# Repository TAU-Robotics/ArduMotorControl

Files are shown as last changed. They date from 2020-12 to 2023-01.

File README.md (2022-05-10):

# Discrete Control Lab
Discrete control experiment developed for the control lab at Tel Aviv University
The setup uses an Arduino Uno micro controller, micro dc gear motor with magnetic encoder and SparkFun Ardumoto shield.

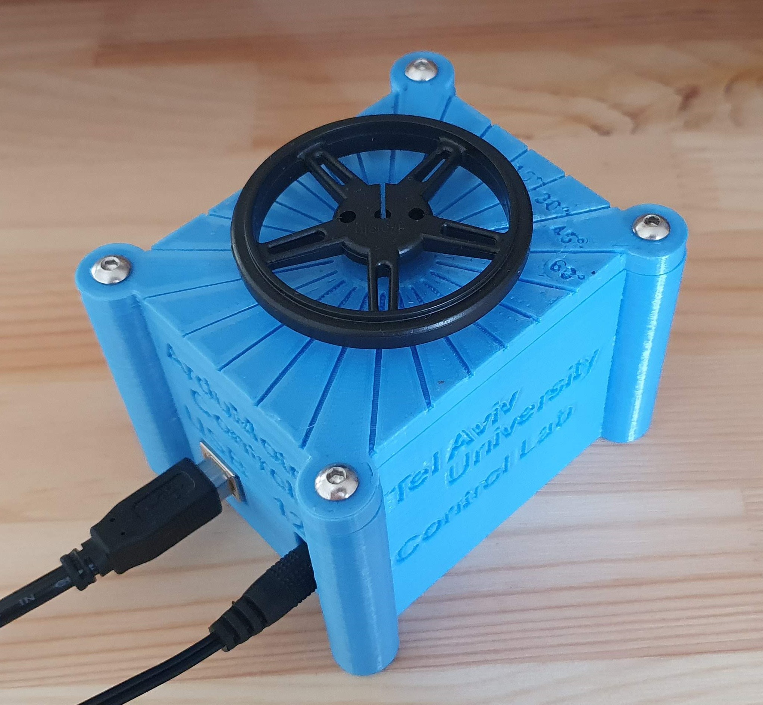
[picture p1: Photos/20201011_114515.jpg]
DC Motor Control Setup


The experiment has two parts, Simulation in simulink matlab and a hardware setup with arduino.

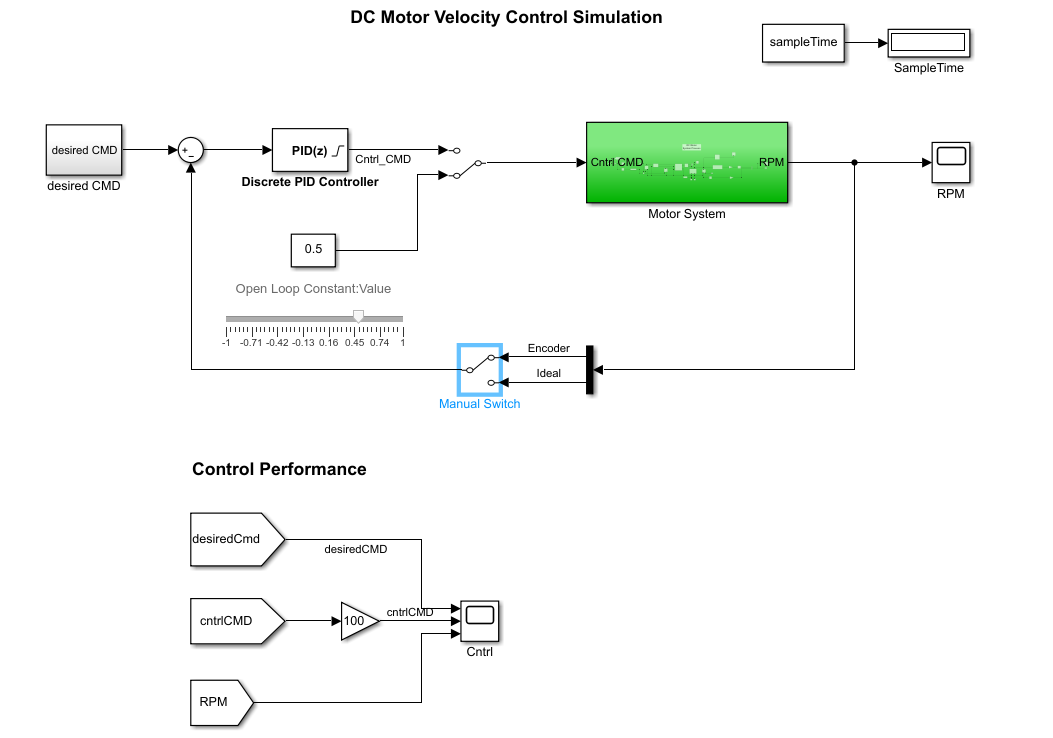
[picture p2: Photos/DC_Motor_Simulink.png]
Simulink


Simulation response:

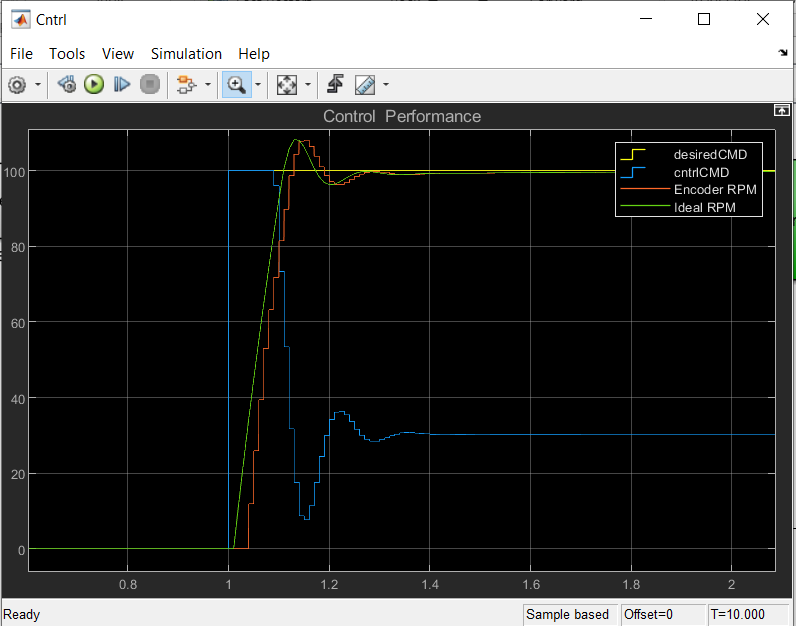
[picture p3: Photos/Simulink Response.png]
Simulink Response


Arduino response:

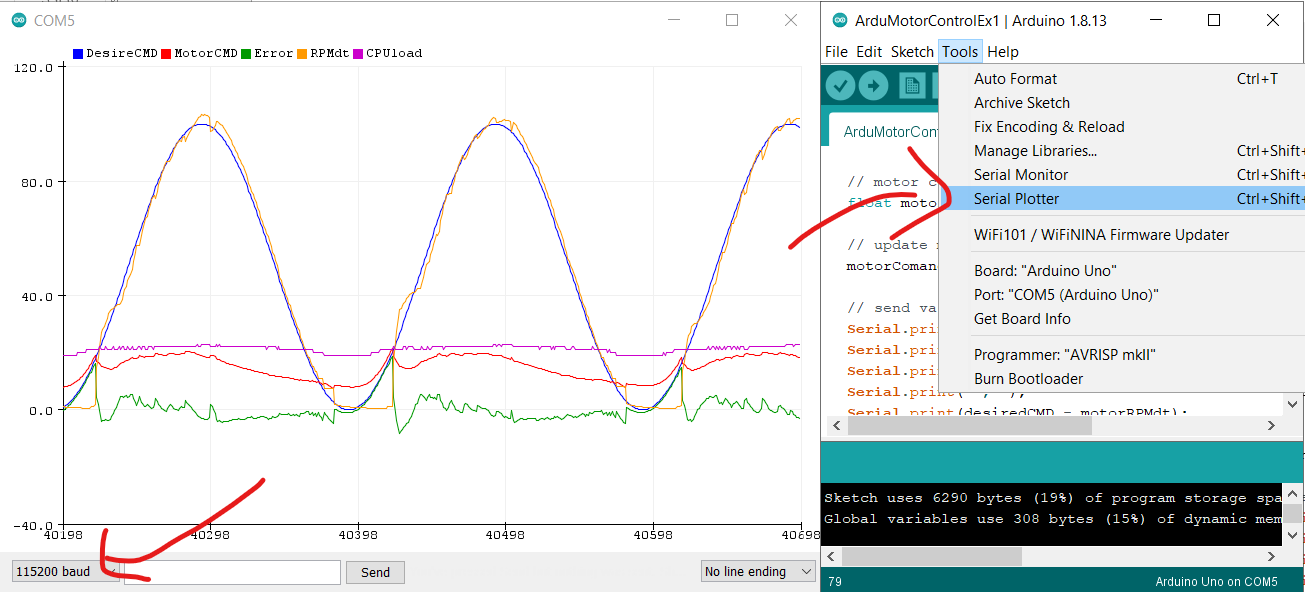
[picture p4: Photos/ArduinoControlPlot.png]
Arduino Response

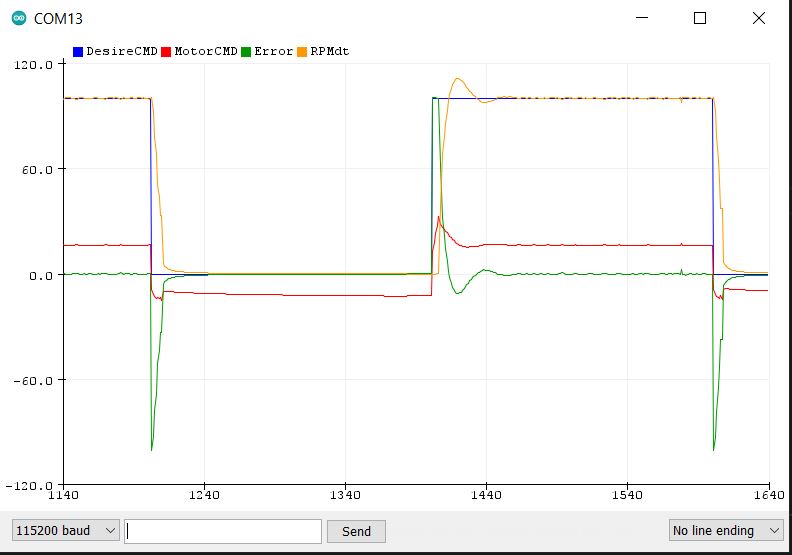
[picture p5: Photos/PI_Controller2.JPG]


# HomeKit Motor Control
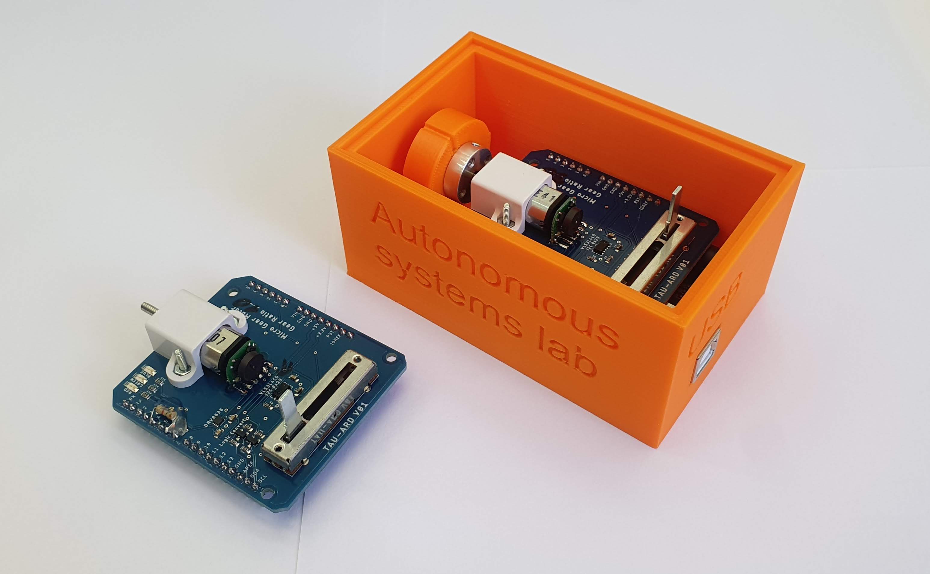
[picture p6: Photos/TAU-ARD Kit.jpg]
TAU-ARD


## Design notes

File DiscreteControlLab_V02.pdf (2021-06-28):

The Iby and Aladar Fleischman Faculty of Engineering Tel Aviv University

# Discrete Control Lab

## 1. Introduction

Modern control systems are realized using a micro controller unit (MCU) and implemented in code. Since an MCU is a discrete system, the control implementation is also a discrete control system. In this experiment, you will get a taste of implementing a simple motor control system using an Arduino development board with the Arduino development environment (IDE).

## 2. System overview

The experiment setup consists of Arduino Uno development board with a carrier shield for motor driver, a DC motor including a gearbox, encoder and a rotation mass. The control is implemented in code using an Arduino development environment in C++. For thorough description of the experiment concepts see literature review chapter. System components:
- Arduino Uno Micro Controller Unit (MCU): https://store.arduino.cc/arduino-uno-rev3
- Motor Driver Shield (H-bridge): https://www.sparkfun.com/products/14129
- DC Motor including Gear box 1:100, 1:50, 1:30 etc: https://www.pololu.com/product/3041
- Magnetic Encoder with 3PPR (Pulses Per Revolution) : https://www.pololu.com/product/3081
- Rotating mass Flywheel:
https://www.pololu.com/product/1420
- 12V Power supply:
- https://www.4project.co.il/product/wall-adapter-power-supply-12v-1a (https://www.4project.co.il/product/wall-adapter-power-supply-12v-1a)

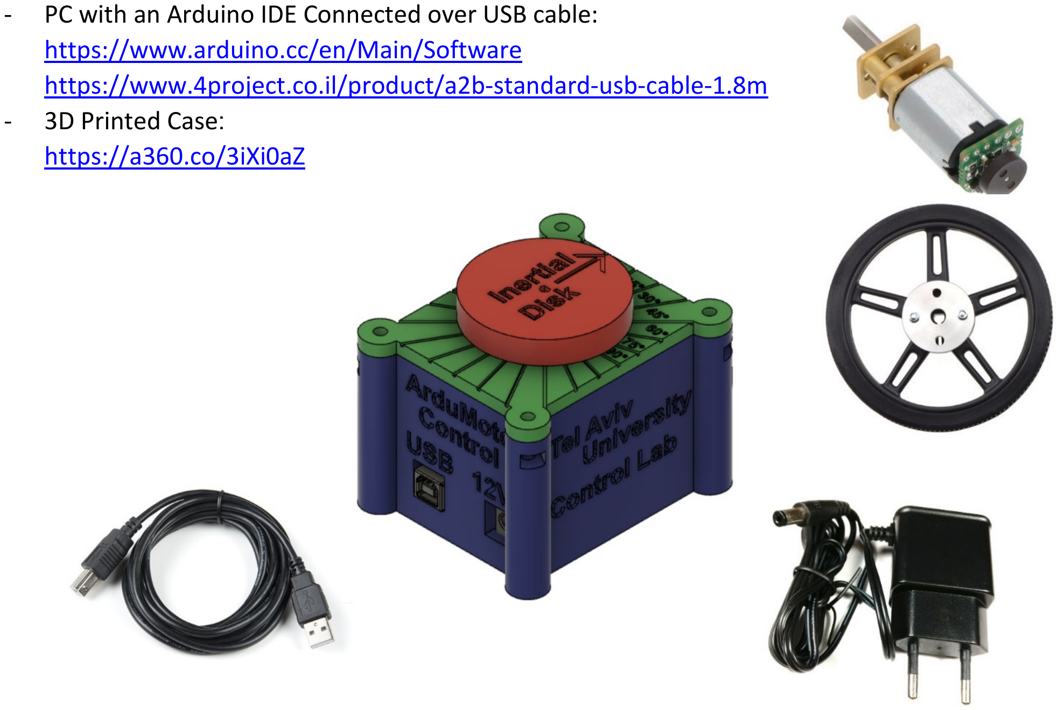
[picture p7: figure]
https://www.arduino.cc/en/Main/Software; - 3D Printed Case: https://a360.co/3iXi0aZ

- PC with an Arduino IDE Connected over USB cable:

https://www.4project.co.il/product/a2b-standard-usb-cable-1.8m

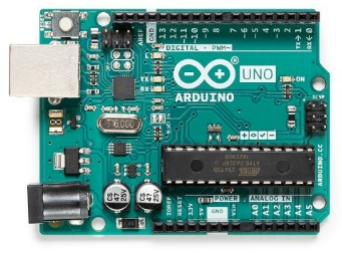
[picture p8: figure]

## 3. Discrete Control Part 1 – Simulation

Throughout this section we are going to explore the concepts of a DC motor system and learn the implementation of a discrete velocity motor control by employing a simulation in Simulink. We will get familiar with the concepts of a sampled system and its influence on the control performance.

3.1 Matlab Simulation review, Open loop.
Start by opening Simulink model: dcMotorControlSim.slx, the model contains open and closed loop implementation of a motor velocity control. The model relies on an initialization script dcMotorControlInit.m, which sets the system sample time variable. Make sure it is present in the work folder which contains the simulation model.

Run the model in open loop with various motor command values. You may change the stop time of the simulation to inf. and change the values through the slider while the simulation is running. Note the motor RPM calculation as measured by the Encoder compared to the Actual RPM.

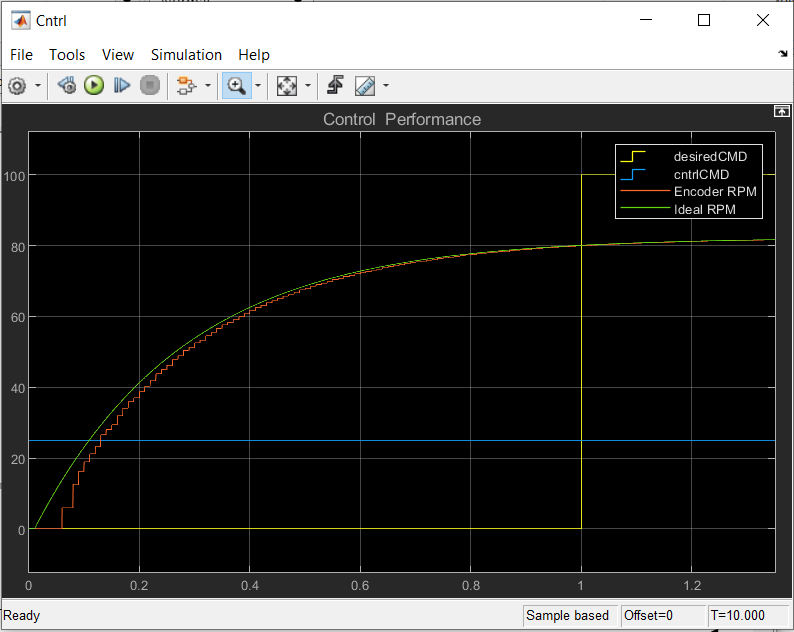
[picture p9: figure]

Change the system’s sampleTime variable and note the influence on the Encoder RPM calculation. You can update the variable through the Command window in Matlab.

Open loop with motor command at 0.25 Simulation sampleTime 0.01 sec

Open loop with motor command at 0.25 Simulation SampleTime 0.1 sec

Open the simulation subsystem named Motor System and review how it is implemented and it`s subsystems. Explain how the encoder works and how the motor velocity is calculated.
Hint: it is implemented at dcMotorControlSim/Motor System/Hall Effect Sensor/Decoder/Pulse decode.

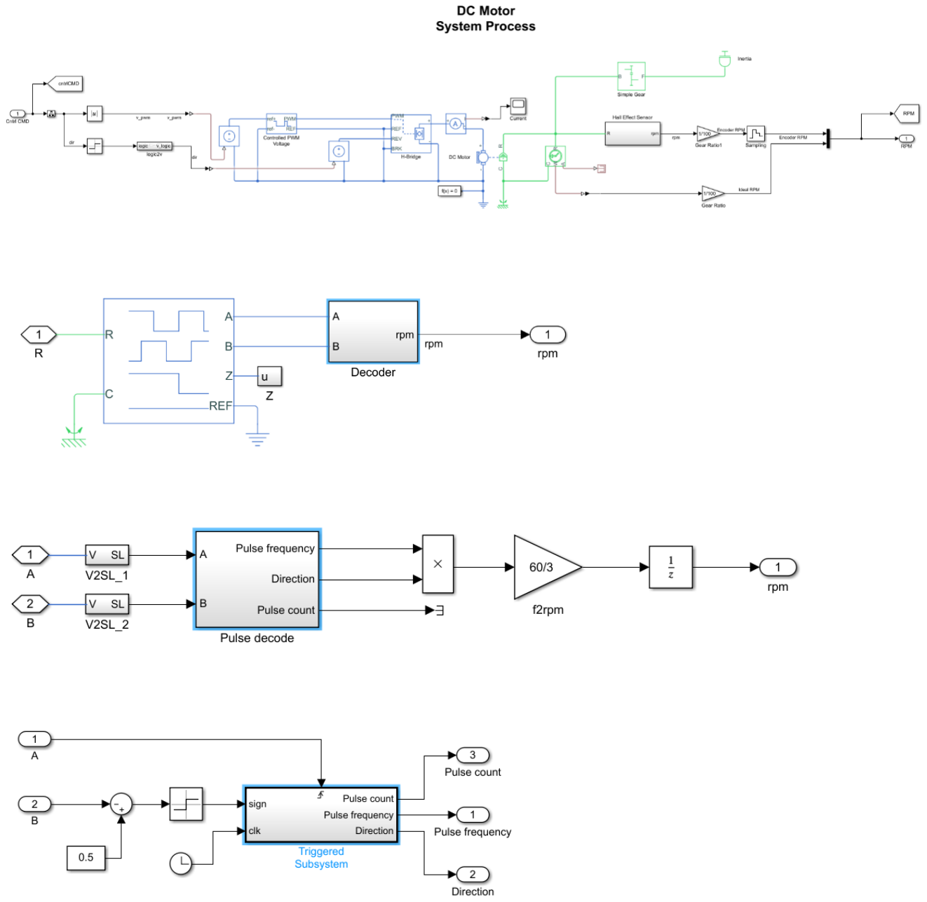
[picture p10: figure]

3.2 Close loop proportional control
For this part of the experiment we will consider the system as a black box -without a known continuous model and learn how to manually tune the controller to achieve the desired system response. First route the model switches to use the signals from the PID controller output, and for the feedback the Ideal RPM value, as depicted in the figure below. Make sure to change back the simulation sample time to 0.01 sec.

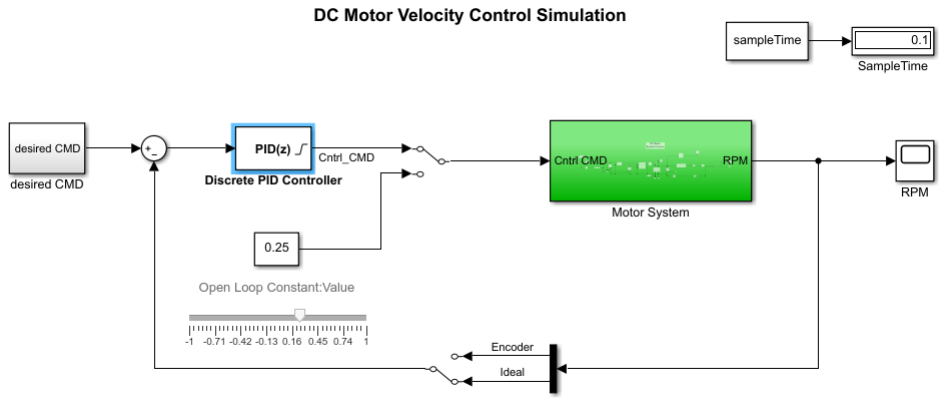
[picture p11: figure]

For this simulation a discrete implementation of the PID controller is used (the block PID(z)). Open the PID block and set it to a proportional gain only.

dcMotorContrlSim.slx, set for PID feedback

Evaluating the initial value for the proportional gain: at the previous section, we have used various motor commands values, which resulted in various motor velocities. From the model review section, you may have noticed that the PWM command is scaled by a value of 0 to 1. Zero for 0-duty cycle – Motor is off and one for 100% duty cycle – Motor works in full power. For a 0.25 value, we got a response of approximately 80 RPM. Meaning that a rational starting value for a step response of 100RPM will be at the proximity of 0.01 gain. The reasoning is that for a starting error of 100 we will get a starting motor command of 1 which is equivalent to 100% duty cycle. Run the simulation with various gains and review the response.

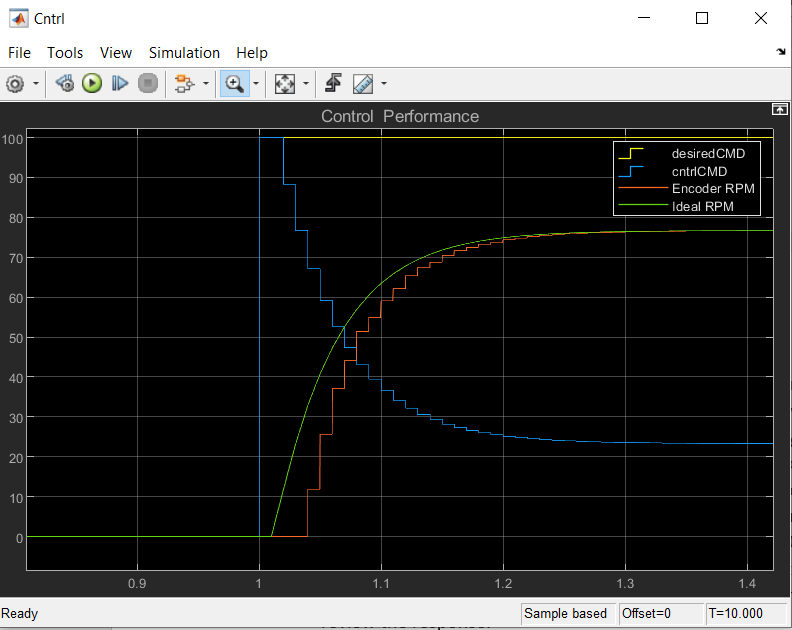
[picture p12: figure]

Close loop response Ideal RPM feedback, kP=0.01 SampleTime=0.01

Choose a proper response gain which results in a slight overshoot and switch to the Encoder feedback. What have happened? The system has lost stability. Perform the experiment with various gains and review the system response you get. Change the sample time and see what happens, run the experiment at different settings (10 gains values and 5 sampleTime values ranging at 0.1-0.001sec) make conclusion for best gains at various sample rate.

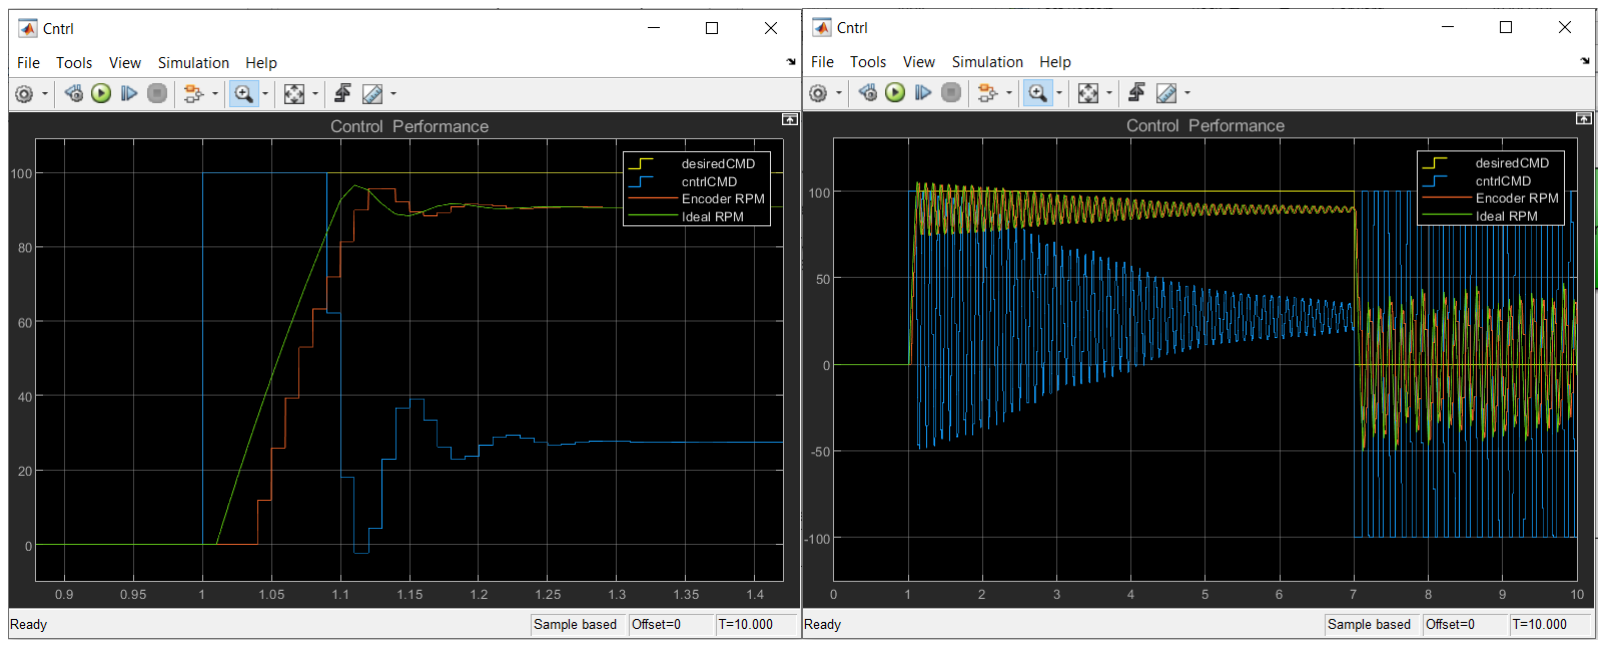
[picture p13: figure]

Because the experiment is based on discrete system implementation and uses an encoder, the system under study can no longer considered to be linear. Write down several rules of thumb concluded from the experiments for a proper proportional gain value.
- Consider the rise time as a function of the control loop frequency (sampleTime).
- Consider the Encoder resolution influence.

Ideal fedback vs Encoder feedback. kP=0.05, sampleTime=0.01

3.3 Close loop PID tuning
After setting a proper response with a proportional gain controller, our next objective is to improve the response by adding the integral and differential component of the PID controller. Set the model to encoder feedback and sampleTime variable of 0.01sec.
First, we would like to eliminate the steady state error. Begin with adding an integral term and scale the proportional gain. Gradually increase the gain and review the system response. If the system loses stability, you may consider to slightly reduce the proportional gain (explain this phenomena). Tune the system until you get a rise time of 0.1 sec, overshoot of up to 10% and settling time of 0.2 sec.

The differential gain isn`t mandatory for a velocity control loop of a DC motor but you may consider adding it to slightly reduce the system overshoot. A good starting point will be at the range of kp*sampleTime.

You may have noticed that the controller is lacking stability at low velocity, which isn`t an issue when using an ideal feedback. In the final report, discuss the reasons for this phenomenon. For the actual experiment we will be using a slightly improved method for velocity estimation based on the encoder feedback, therefore the simulation will be slightly more robust at low velocities.

3.4 PID code implementation
Open Simulink model dcMotorControlSimPIDcode.slx. Note that it has a Matlab function for implementing the PID control in code. Route the system Control command to the Matlab PID function. It has the implementation of proportional gain only. Review the code and complete it for the full PID implementation (add the integral and derivative terms). Compare the response between the Simulink block and the code implementation that you have just completed for identical PID values.

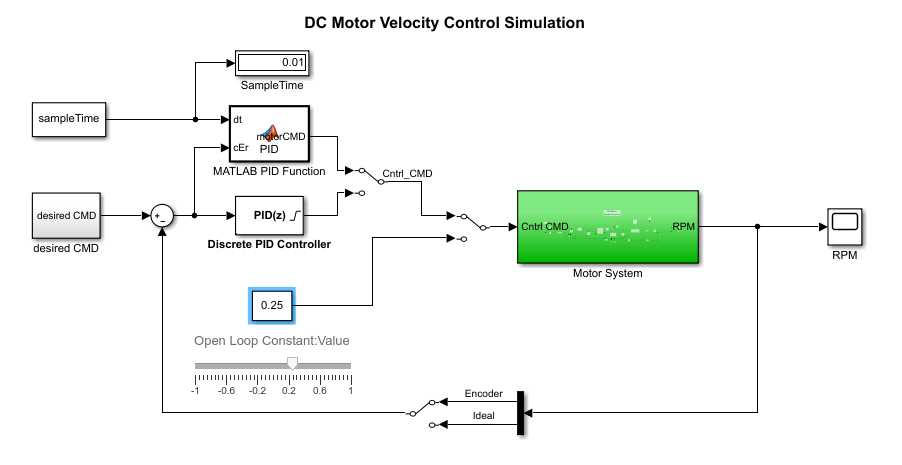
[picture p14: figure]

function motorCMD = PID(dt,cEr)
% persistant variables persist between function calls. similar to % static variable declaration in c
persistent lEr cdEr ciEr;
if isempty(lEr) %initialize variables for first run of the code. lEr = 0; % previous error initialization
cdEr = 0; % differantional error initialization
ciEr = 0; % integral error initialization
end
% control coeficients
kp = 0.025;
% clip integrator error
if (ciEr > 10)
ciEr = 10;
elseif (ciEr < -10)
ciEr = -10;
end
% update control command
motorCMD = kp*cEr;
% clip motor command
if (motorCMD > 1)
motorCMD = 1;
elseif (motorCMD < -1)
motorCMD = -1;
end
% update last error variable before next iteration lEr = cEr;

## 4. Discrete Control Part 2 – Hardware

In this section we will implement the control laws using the Arduino IDE (Integrated Development Environment) in C++ and monitor its response by employing the embedded tool of the IDE. Since most of the modern control systems use a micro controller for motor control this experiment will be a good peek into the actual implementations of the learned theories during the classes.
4.1 Getting started with Arduino / Arduino IDE
Open Arduino IDE, either use the desktop icon, or search for the application.

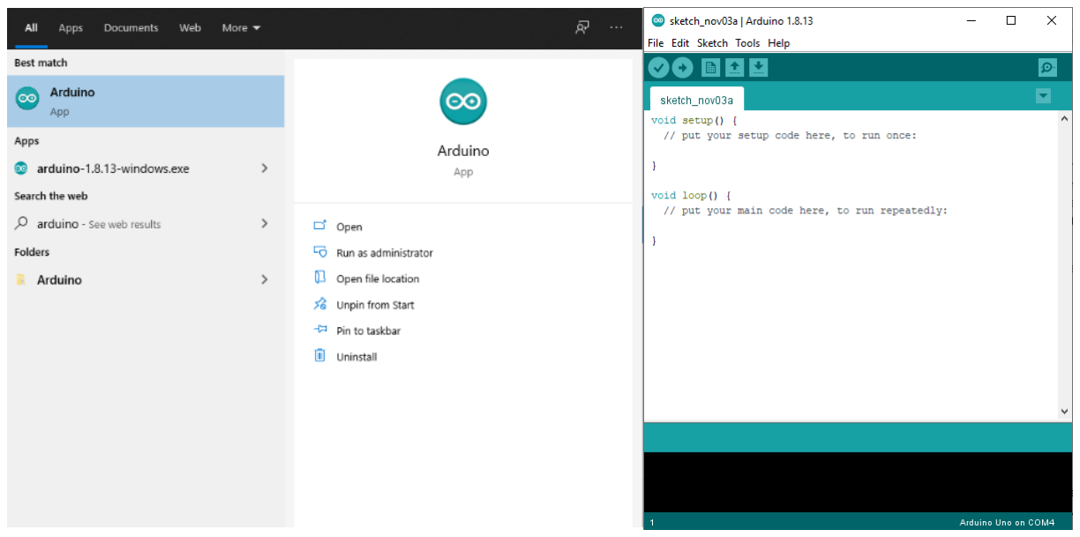
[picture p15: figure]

Connect the USB cable to the ArduMotoControl Box. Since the micro controller implement the last code that has been uploaded, you may see the motor start spinning upon voltage application. Make sure that the 12V power plug is also connected. When you finish working with the setup, disconnect the power supply and the USB cable.

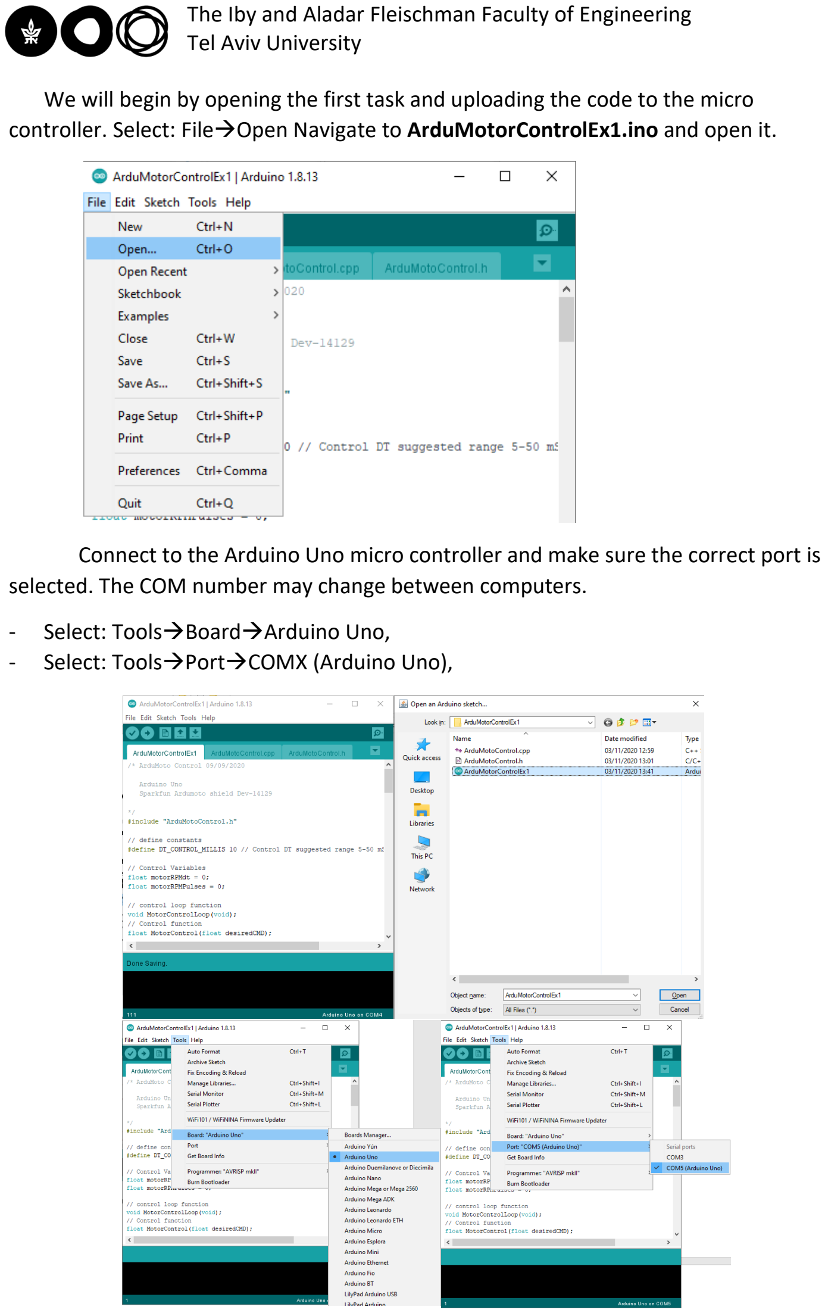
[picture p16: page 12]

We will begin by opening the first task and uploading the code to the micro controller. Select: File→Open Navigate to ArduMotorControlEx1.ino and open it.

Connect to the Arduino Uno micro controller and make sure the correct port is selected. The COM number may change between computers.
- Select: Tools→Board→Arduino Uno,
- Select: Tools→Port→COMX (Arduino Uno),

Upload the example to the micro controller by pressing upload button→. If everything is successful than you should see the “Done uploading” message and the motor will start spinning with a Sine Profile.

View the System response using the Serial Plotter tool. Make sure the baud rate is set to 115200 otherwise you get gibberish on the screen instead of the desired data. If everything has started correctly you will see the legend of the data on top of the graph, if it is mixed due to incorrect baud rate or some other start up issue you may reopen the Serial Plotter. It will reset the controller and start correctly.
- Tools→ Serial Plotter

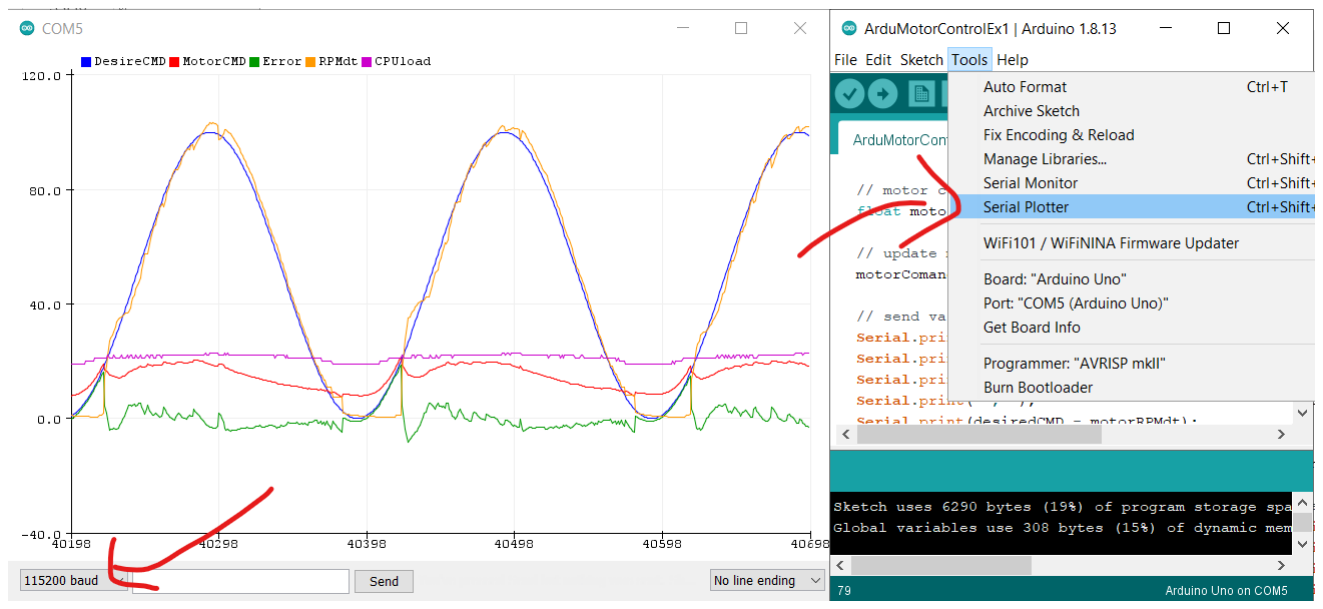
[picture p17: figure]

You may notice that the RPM readings do not correspond to the actual rotating speed of the disc. Don`t worry, in the next section we will set the correct gear ratio for the specific box and verify that it is corresponds to what we perceive.

Sometimes during the lab, you will be required to record a series of data, for that we will use the Serial Monitor tool. Each time you open the Serial Monitor or the Serial Plotter tool it will reset the micro controller and restart the latest code uploaded to it. When you open the Serial Monitor you will be able to see the streamed values, make sure the baud rate is correct and in order to make a recording deselect the Auto-scroll feature or wait for the motor to finish spinning. Select the data set by pressing CTRL+A and CTRL+C, Past the data set into a text file you have created on the pc.
- Tools→ Serial Monitor

You may notice that the recorded data has unfished data at the button of the data set or some values prior the variable names, which are of a previous session (prior reopening the Serial Monitoring tool). In order to make it easier to import the data into Matlab we will preprocess the data set by deleting all the values prior the variable names and the last unfinished line.

At this point importing the data into Matlab is easy using the Matlab Import Data tool. Press the Import Data option select the processed file, make sure the Comma separating is selected and import the samples to the workspace. To preview the recorded samples, use the Matlab stacked plot option. Right click on the data set in Matlab select Plot Catalog and choose the stacked plot option.

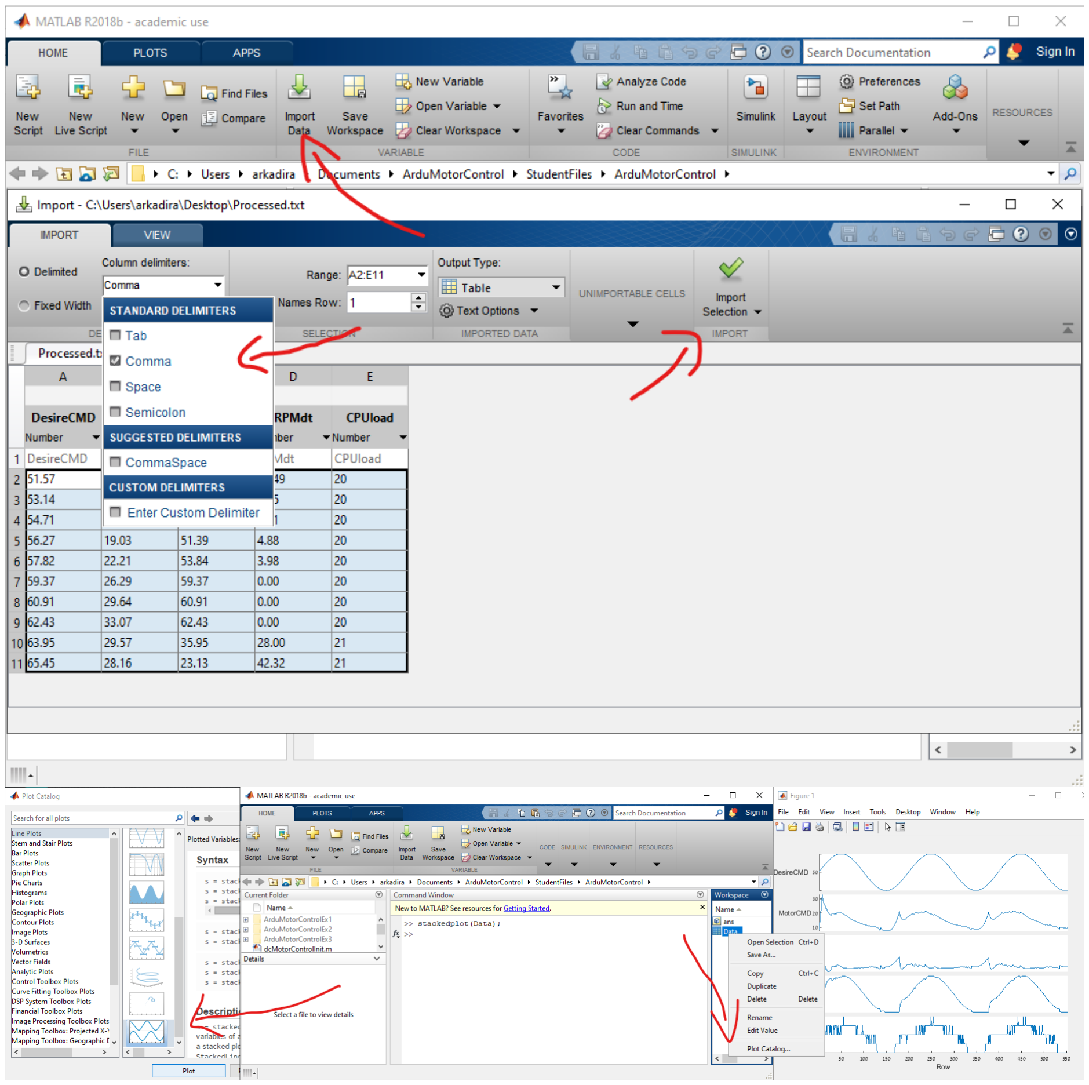
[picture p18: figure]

4.2 Code Review
The Experiment is implemented in C++ in order to handle the control section we will review the general approach for the code. When opening the ArduMotorControlEx1 you may have noticed the added files ArduMotoControl.cpp and ArduMotoControl.h those are the library files for the experiment and they have the implementation of the functions available at the main file ArduMotorControlEx1 including the motor driver handling and the encoder reading. You may review them and the comments for each function but for the experiment we will focus at the code in the main file.
The file Starts with the #include line for the library following some variables and function declaration. Make notice of the following variables, function.
- DT_CONTROL_MILLIS – Sets the control interval for the experiment similar to the simulation. Take care not to exceed the recommended settings as not to overload the CPU. (Nothing will break but the controller will lose its stability)
- GEAR_RATIO – Sets the gear ration for the specific setup. The gear ratio is written on the box of the experiment.
- TIMEOUT – Sets the time for the experiment in seconds.
- motorRPMdt – Is a global variable for the motor velocity based on the time interval between encoder pulses.
- motorRPMPulses – Is a global variable for the motor velocity based on the number of pulses occurred between the calls of the readRadSEncoder() function
- MotorControlLoop – Is a function which is called every controlled interval set by the DT_Control_Millis.
- MotorControl – Is the actual function for the Control implementation called inside the MotorControlLoop function.
Note the sections which start and end with the comment Student Code / Student Function, they indicate the sections which are available for modification so as not to harm the general flow of the rest of the code.

4.3 Open loop velocity response & Encoder readings
For this section we will evaluate the system response and understand the limitation of working with a cheap encoder, start by Opening the ArduMotorControlEx2.ino sketch in the Arduino environment. Review the code and update the GEAR_RATIO parameter to correspond to the gear ratio written on the box.

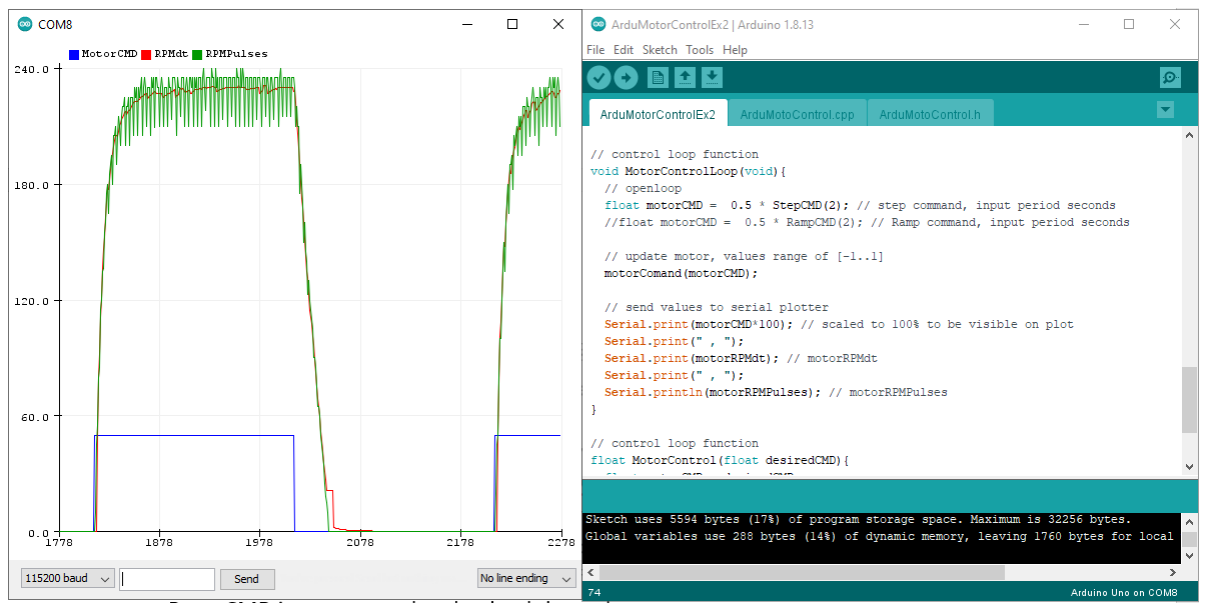
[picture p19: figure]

Find the Open loop command inside the MotorControlLoop() function. We will work with a ramp command and step command functions which are implemented in the library, the input to the function is the time period and the output is a command in the range of [0..1]. Verify that the StepCMD() function is uncommented with a gain of 0.5 and the RampCMD is commented and upload the code. Open the Serial Plotter and view the system response. The plot contains the desired command, the velocity
measurement using the two approaches, time between encoder pulses, and number of pulses per function call RPMdt, RPMPulses.
For a gear ratio of 1:100 you should get RPM value of ~210 RPM for a gear ratio 1:30 approximately ~700 RPM. To verify that you have set the GEAR_RATIO correctly you may set a lower open loop gain and count the number of motor revolutions for a period of time. Than estimate if it corresponds to the measured value.
RPM = Revolution*60/Time[s].

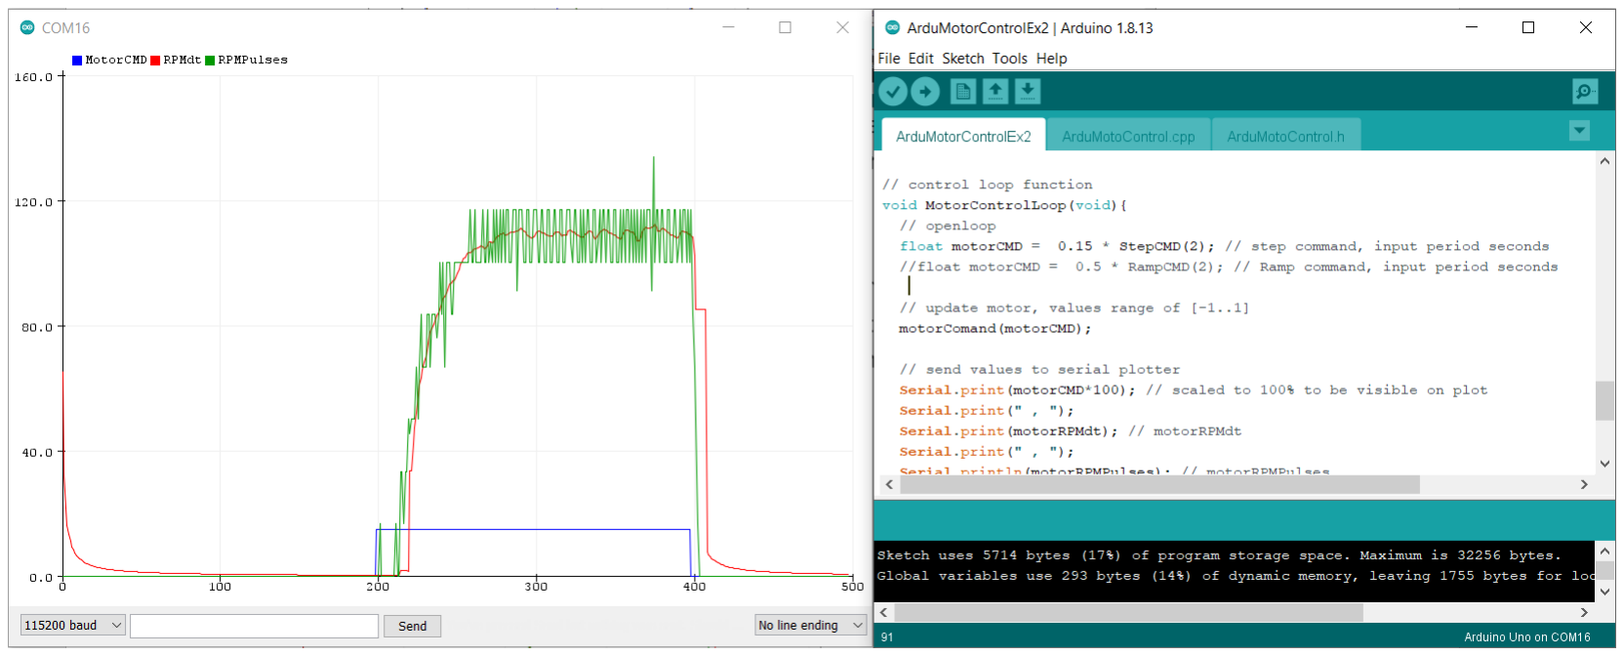
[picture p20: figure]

Change the command to the rampCMD by uncommenting the RampCMD function and commenting the StepCMD function. Upload the updated code to the micro controller and view the response using the Serial Plotter.

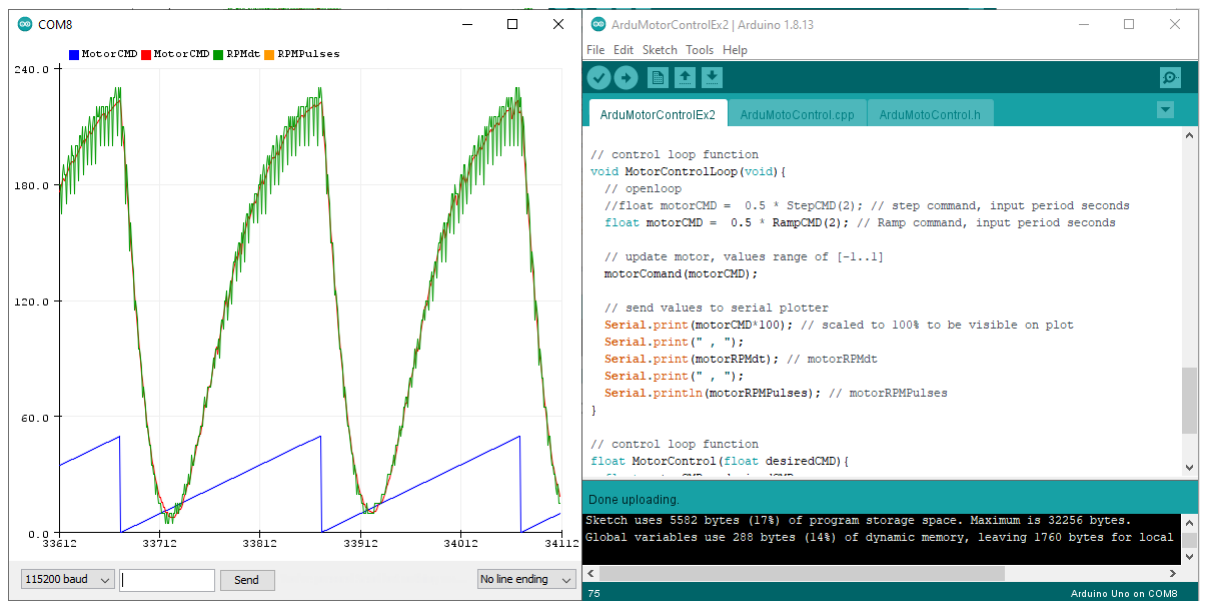
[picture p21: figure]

Modify the code by changing the gains and the time period generating various commands and view the responses you get. In addition, change the control frequency by modifying the value of DT_CONTROL_MILLIS.
- What is the minimal command for the motor to start moving?
- What is the maximum velocity?
- What can you say about the two methods for velocity measurements? Which is better at high speeds and which for lower speeds, how the control frequency influences the results?

In the final report:
Prepare a recording for analysis in Matlab of a ramp response with a period of 5 seconds, and gain of 0.25, at two control periods, 10ms and 100 ms. Generate plots comparing the measured RPM of both methods.
- A plot containing RPMPulses at the two measured control intervals
- A plot containing the difference between RPMPulses and RPMdt as a function of the motor command for both control intervals.
Settings:
float motorCMD = 0.25 * RampCMD(5);
#define DT_CONTROL_MILLIS 100

#define TIMEOUT 5

Prepare a recording of a step response at a gain of 0.25 and period of 2 seconds. Plot the response in Matlab and mark the rise time of the system.
Settings:
float motorCMD = 0.25 * StepCMD(2);
#define DT_CONTROL_MILLIS 2

#define TIMEOUT 6

4.4 Close loop proportional velocity control
For this section we will implement a simple proportional control command and tune it`s gain. Start by Opening the ArduMotorControlEx3.ino sketch in the Arduino environment. Review the code and find the MotorControl() function. Understand the controller implementation and start with a logical value for the proportional gain – Remember the concepts described at Part 1 - Simulation.
Run a step response of approximately 1/3 of the maximum velocity at open loop. For example, 100RPM for a 1:100 gear ratio setup, and 300RPM for a 1:30 gear ratio setup. Set the selected gain (Hint: ~ 0.01 for 1:100 gear and ~0.0033 for 1:30 gear). View the response using the Serial Plotter tool.
float desiredCMD = 100 * StepCMD(2);
#define DT_CONTROL_MILLIS 10

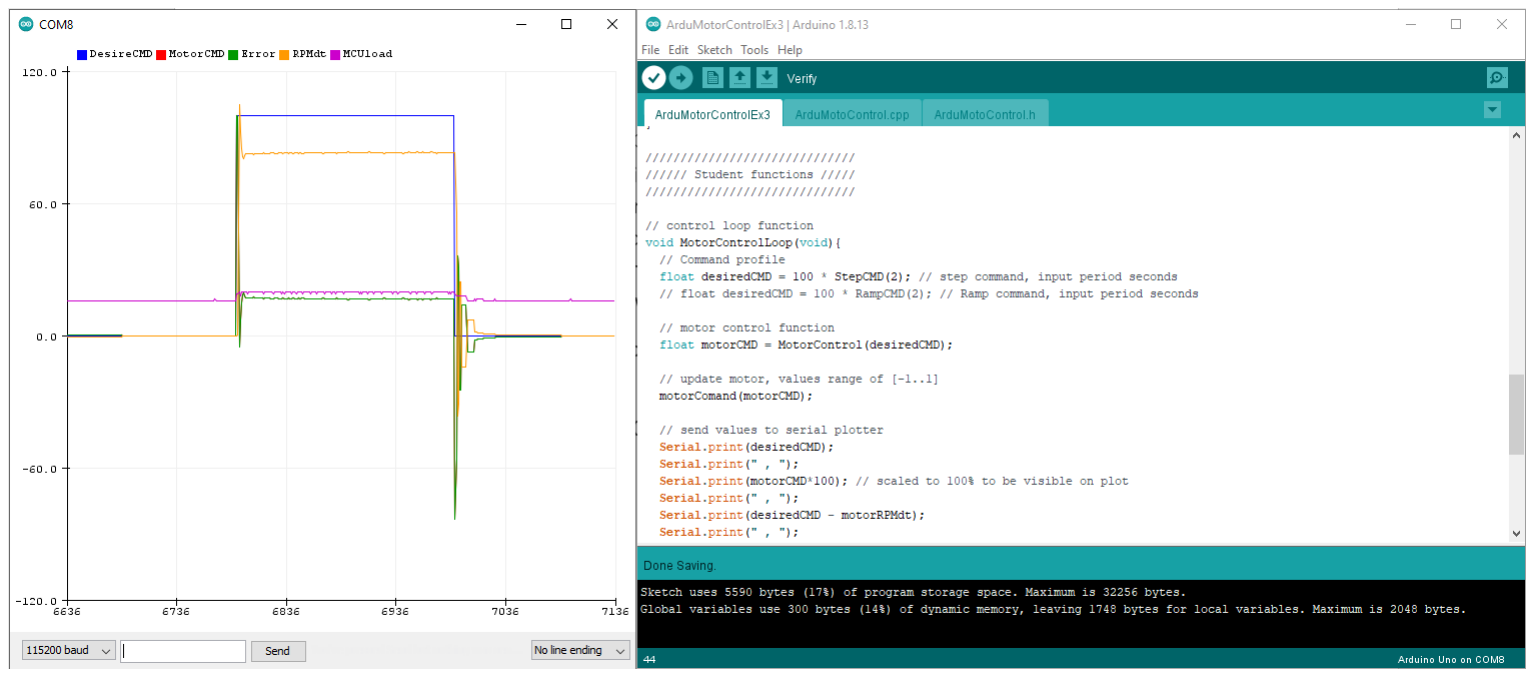
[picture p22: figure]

Change the DT_CONTROL_MILLIS value to 50 and see what happens. Explain the behavior and adjust the gains until you reach a stability. Find the stable gains for DT_CONTROL_MILLIS of 10,25,50 milliseconds. Record each of the responses you get with the final coefficients for each of the control interval for later analysis in Matlab. In the final report generate a plot containing the 3 step responses generated previously and determine the rise time for each.
In order to understand the potential stability for various speeds we will use the rampCMD() function. Run a ramp response at ~1/3 open loop maximum velocity with 10 milliseconds control interval. With the stable gain found for this control interval.
float desiredCMD = 100 * RampCMD(2);
#define DT_CONTROL_MILLIS 10

From the open loop experiments we have seen that the encoder resolution is far from perfect at the lower velocities. The ramp function helps identify those issue and will allow us to easily tune the gain to meet stability for the desired control range. Adjust the proportional gain value until a steady response is achieved for the ramp command similar to the plot below. We will be using this value as a starting point for the PID controller next section.

4.5 Close loop PID velocity control
Open the ArduMotorControlEx4.ino sketch in the Arduino environment. Review the code and find the MotorControl() function. Understand the PID controller implementation and start with a logical value for the integral gain – Remember the concepts described at Part 1 - Simulation. Tune the value until a slight overshoot is achieved for a step response of ~1/3 open loop maximum velocity and control interval of 10 milliseconds. Record the response for later analysis in Matlab.
In the final report calculate the rise time overshoot and settling time of the step response.

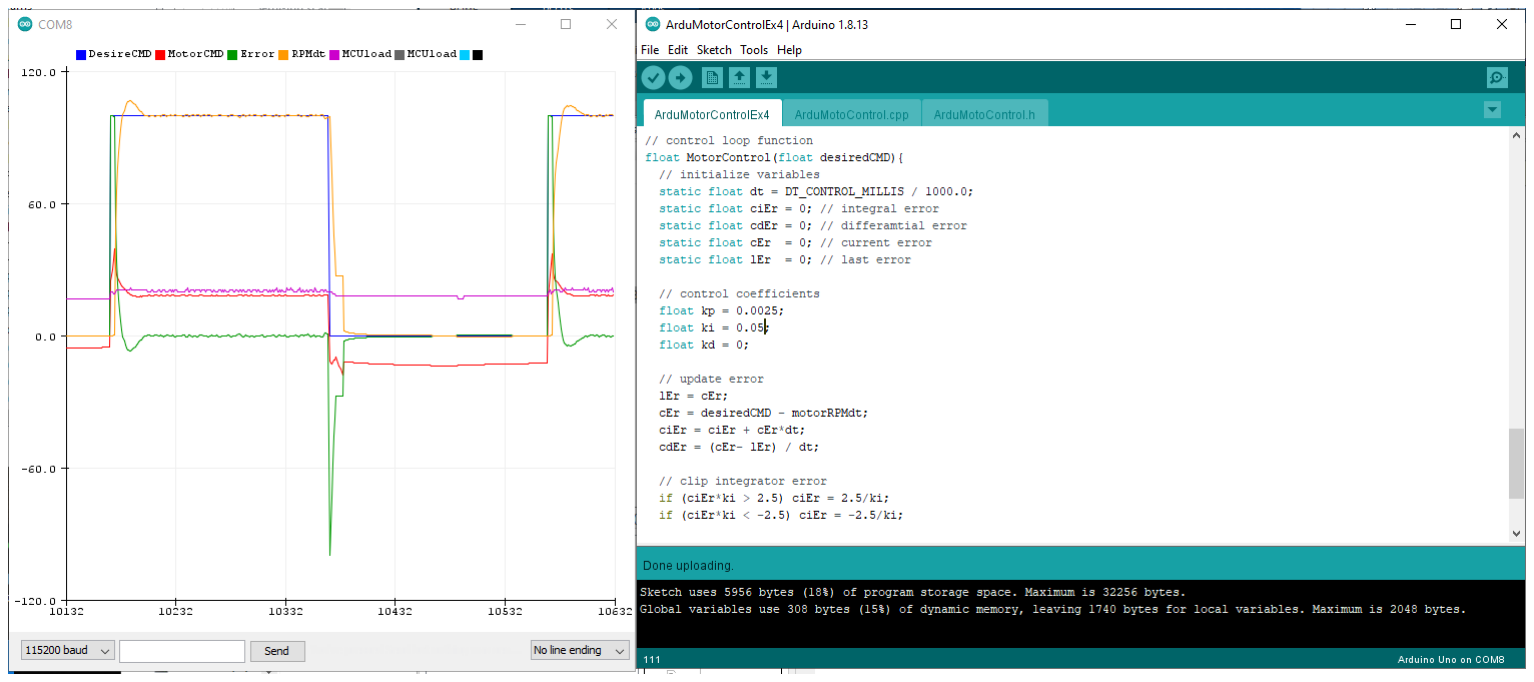
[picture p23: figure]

Run the ramp Response with the same values. Record the response and in the final report evaluate the instability point. What happens to the encoder values around this point? Compare this point`s motor command to the minimal command needed to start the motor spinning found in the open loop experiment, write your conclusions.

Usually the differential gain isn`t required for the velocity control loop of a dc motor, and at the current example it has a very simplified implementation as such adding it will mainly interfere with the motor control implementation. But in order to understand the concept and the simplified implementation we will run a simple example. Start by setting the differential gain to a logical value using the concepts described at Part 1 – Simulation. Increase the value slightly until it`s influence will be noticed but without losing stability. (in the range of kp*sampleTime[s] ~ 0.00001)
In the final report, record the results and generate a plot in Matlab marking its influence. Suggest a better implementation of a differential element. Hint – overcoming the error of a numerical differentiation.

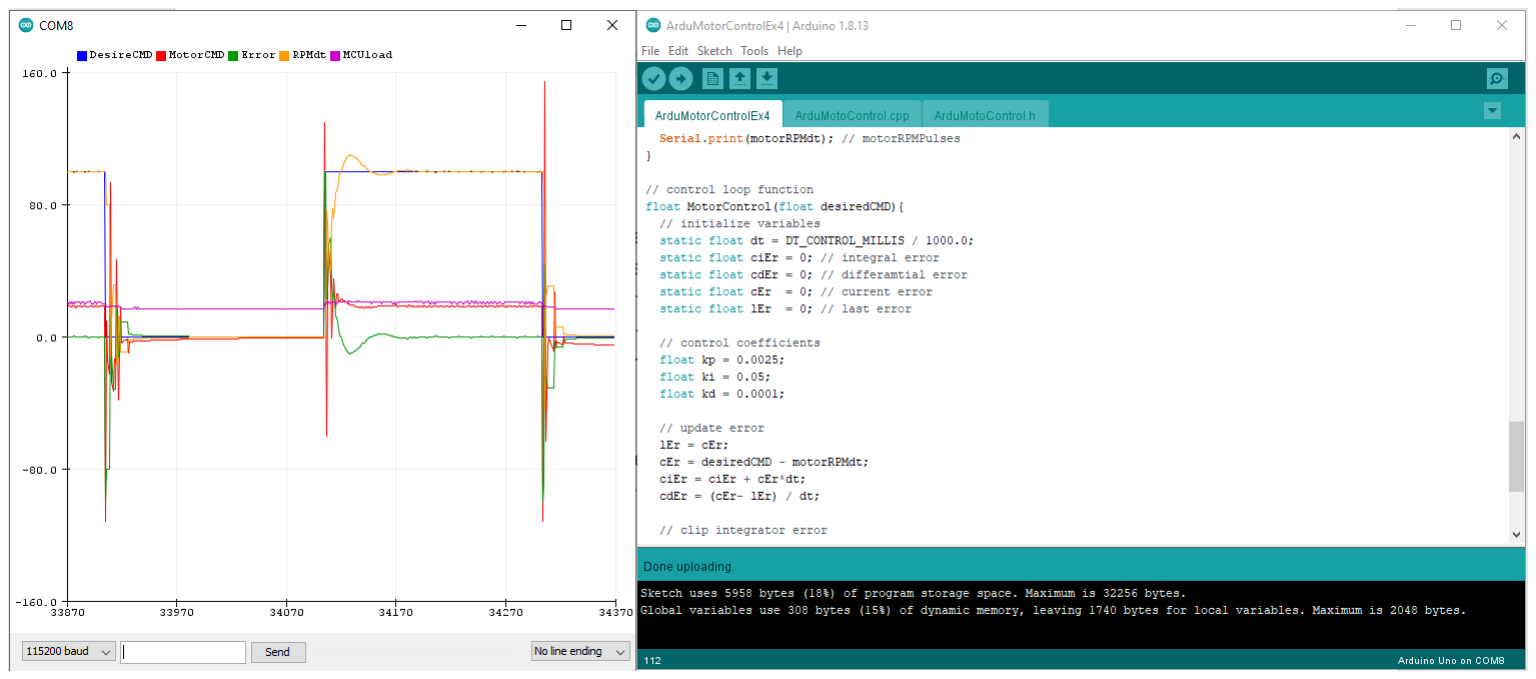
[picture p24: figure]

4.6 Control loop frequency influence on control performance
For this section we will use the PI coefficients found at the previous section with the differential gain set to zero. (PI Controller). Run a series of step responses at ~1/3 open loop maximum velocity at various Control intervals DT_CONTROL_MILLIS. Start with 10ms and increase the value until you lose stability.

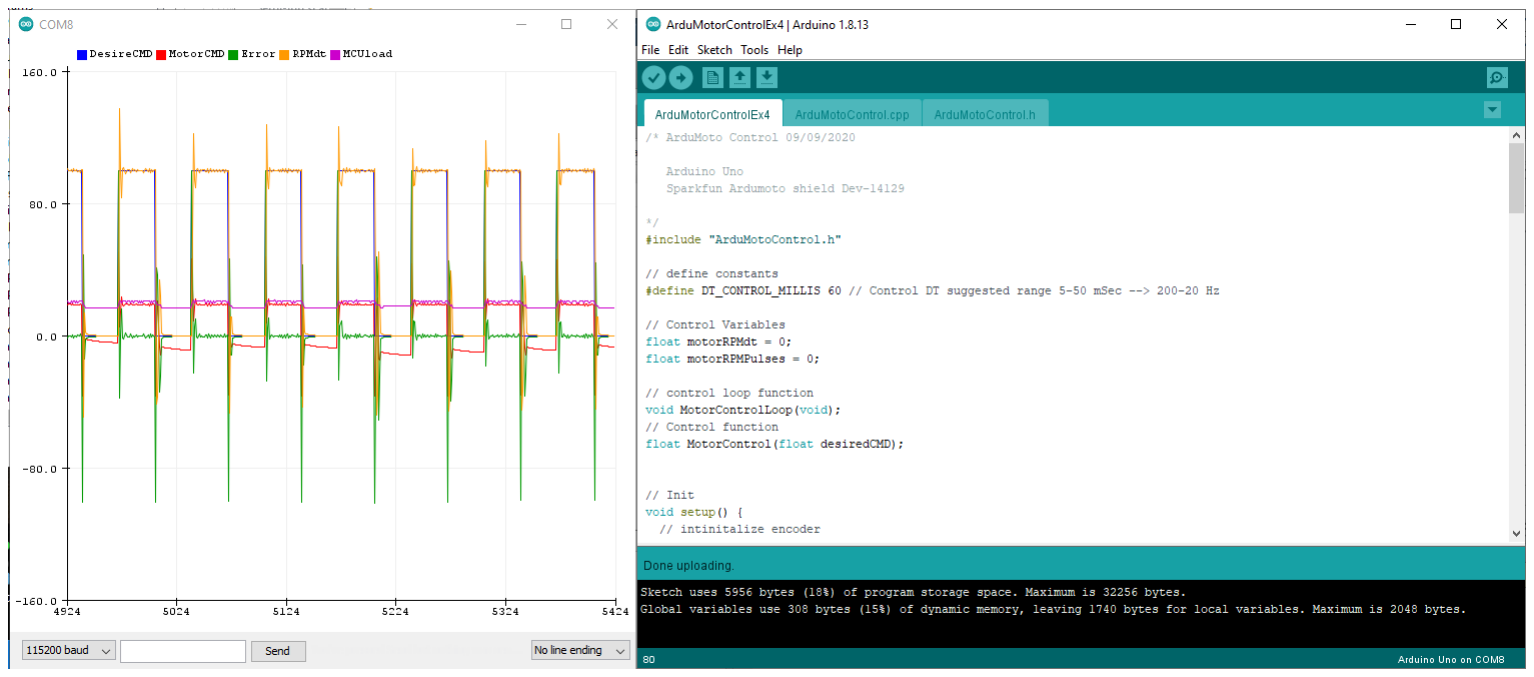
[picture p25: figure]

Record the experiment with 3 settings of control interval, 10ms last stable value and a middle value.
In the final report generate plots in Matlab marking the rise time and the settling time. Compare the values to the control interval. Write you conclusions regarding suggested control loop frequency.

4.7 (Bonus) Comparison between simulation and actual setup
Run the simulation with a PI controller with the gains found for the hardware setup at a 10ms control interval. Generate a Matlab plot comparing the step response of the simulation and the hardware (Remember to update the gear ratio in the simulation if needed). The simulation is modeled based on the theoretical parameters of the hardware model, suggest a method to improve the simulation model to meet the actual hardware.

4.8 (Bonus) Load influence on system response.
Evaluate the system response by adding 100g inertial disc on top of the system. Use the best setting for a PI controller found in previous sections and run a step response with and without the added disc. Record the responses.
In the final report generate a plot in Matlab comparing the responses. Mark the rise time and the settling time. Write you conclusions.

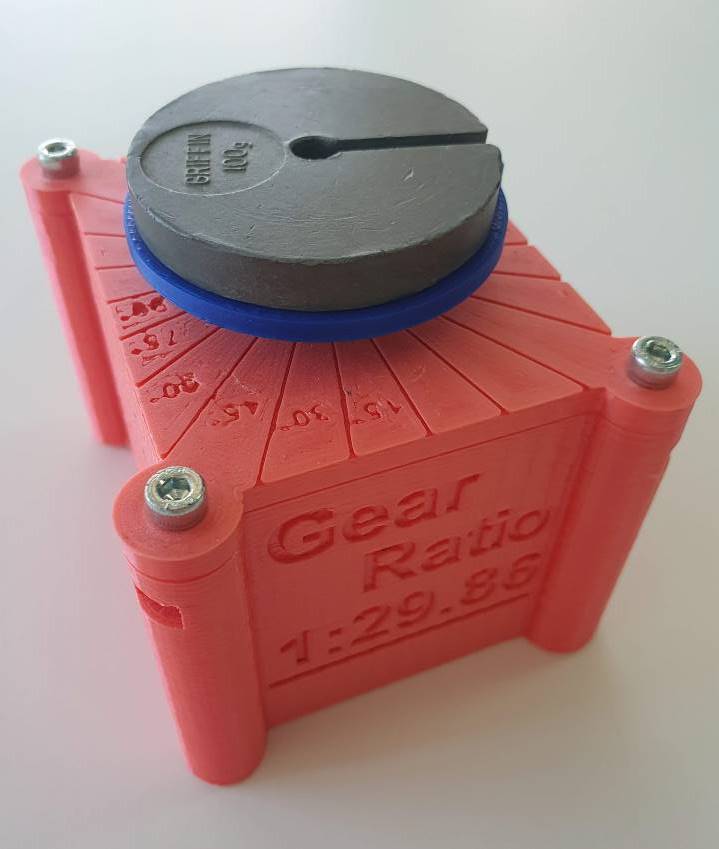
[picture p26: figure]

4.9 (Optional) Further experimentation with the system.
- Tune the coefficients for the added disc.
- Compare the responses for a ramp command.
- Compare the responses for sine command
- Test how adding a differential controller influences the system response with the added disc.
- Investigate the disc influence on the encoder behavior / readings.
- Evaluate a different gear ratio box. Tune the PI controller and compare the influence of the added disc.

## 5. Literature

5.1 Micro Controller Unit (MCU)
A microcontroller (sometimes called an MCU or Microcontroller Unit) is a single Integrated Circuit (IC) that is typically used for a specific application and designed to implement certain tasks. Products and devices that must be automatically controlled in certain situations, like appliances, power tools, automobile engine control systems, and computers are great examples, but microcontrollers reach much further than just these applications.
Essentially, a microcontroller gathers input, processes this information, and outputs a certain action based on the information gathered. Microcontrollers usually operate at lower speeds, around the 1MHz to 200 MHz range, and need to be designed to consume less power because they are embedded inside other devices that can have greater power consumptions in other areas.
A microcontroller can be seen as a small computer, and this is because of the essential components inside of it; the Central Processing Unit (CPU), the Random-Access Memory (RAM), the Flash Memory, the Serial Bus Interface, the Input/Output Ports (I/O Ports), and in many cases, the Electrical Erasable Programmable Read-Only Memory (EEPROM).

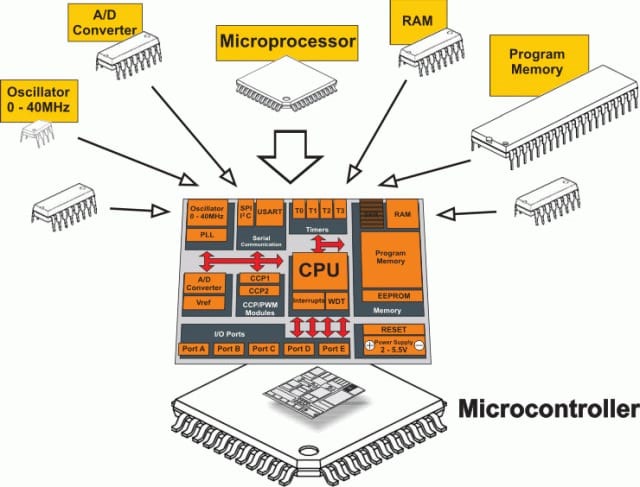
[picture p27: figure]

Figure: Parts of a microcontroller. (Source: Max Embedded)

5.2 Arduino Development Board and Environment
Arduino is an open-source electronics platform based on easy-to-use hardware and software. Arduino boards can read inputs, amount of light on a sensor, a press on a button, or the arrival of a Twitter message and turn this into an output, for example, activating a motor, turning on an LED or publishing something online. You can tell your board what to do by sending a set of instructions to the microcontroller on the board. To do this use the Arduino programming language and the Arduino Software (IDE).

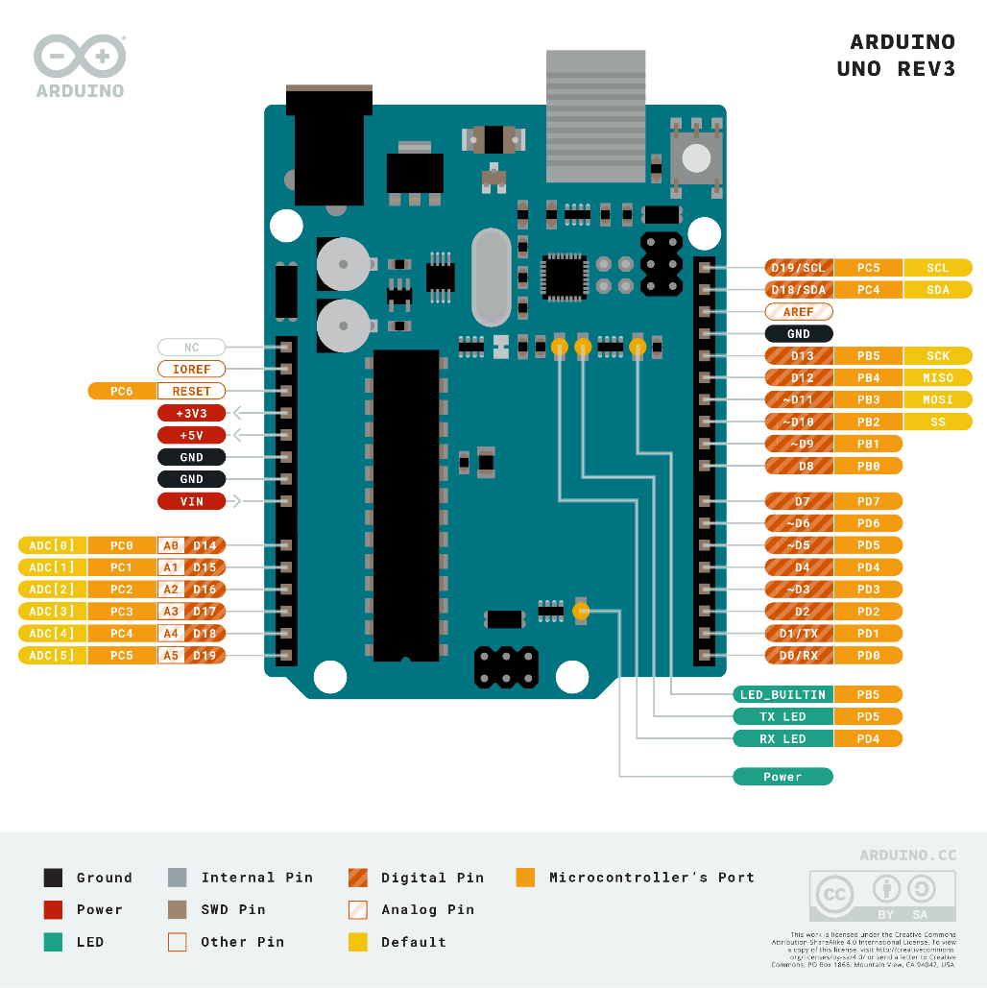
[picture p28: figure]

Arduino Uno is a microcontroller board based on the ATmega328P . It has 14 digital input/output pins (of which 6 can be used as PWM outputs), 6 analog inputs, a 16 MHz ceramic resonator, a USB connection, a power jack, an ICSP header and a reset button.

Microcontroller | ATmega328P (http://ww1.microchip.com/downloads/en/DeviceDoc/ATmega48A-PA-88A-PA-168A-PA-328-P-DS-DS40002061A.pdf)
Operating Voltage | 5V
Input Voltage (recommended) | 7-12V
Input Voltage (limit) | 6-20V
Digital I/O Pins | 14 (of which 6 provide PWM output)
PWM Digital I/O Pins | 6
Analog Input Pins | 6
DC Current per I/O Pin | 20 mA
DC Current for 3.3V Pin | 50 mA
Flash Memory | 32 KB (ATmega328P) of which 0.5 KB used by bootloader
SRAM | 2 KB (ATmega328P)
EEPROM | 1 KB (ATmega328P)
Clock Speed | 16 MHz

The Arduino environment (IDE) has an extensive support for various micro controllers and includes a core library, which simplifies the programming of microcontrollers.

An introduction to the programming environment is available at https://www.arduino.cc/en/Guide/Environment
The core function and variables descriptions are available at https://www.arduino.cc/reference/en/

5.3 DC Motor
A DC (Direct Current) motor is a type of motor that will cause the motor shaft to rotate around its longitudinal axis when applying an electric current between its terminal pins. Thus, the DC motor is a type of actuator that transforms electrical current into rotational motion.

There are two parts inside a motor: the rotor (the shaft is part of this) and the stator. Looking at the cross-section of a motor, you can see that the rotor is the moving part and the stator is the static part. The stator and the rotor use both permanent magnets and electromagnets. Depending on the type of motor, the stator can be a permanent magnet while the rotor is an electromagnet, or vice-versa. Turning on the electromagnet creates attraction and repulsion forces that make the motor spin. The DC motor spins when we apply DC voltage through its two terminal pins. We can vary the speed of the motor by changing the voltage level. Motors can run in both directions just by reversing the direction of the current.

5.4 Motor Driver H-Bridge
Most electric motors need a higher voltage than can be provided by a microcontroller. To control a DC motor from a microcontroller, you’ll need to use a driver. This can be a transistor, a relay or an H-Bridge. The Arduino Motor Carrier uses H-Bridges to drive the DC motors.
The H-Bridge is an electronic circuit that contains four transistors arranged so that the current can be driven to control the direction of the spin and the angular speed. There is a more in-depth explanation of the H-Bridge in section 3.1.4. It is common practice to use PWM (Pulse Width Modulation) signals to control the speed of a motor instead of providing analog voltages.
With the Arduino IDE, if you want to just turn a DC motor on and off, you can use a digitalWrite command with HIGH for ON and LOW for OFF. If you instead want to modify the speed of the motor, you can use the analogWrite command and one of the PWM pins.
5.5PWM
Pulse Width Modulation, or PWM, is a digital modulation technique commonly used to control the power supplied to electrical devices, like motors. The modulation technique consists of changing the width of a periodic signal’s pulse. The width of the pulse is referred to as the duty-cycle and goes from 0% (minimum width) to 100% (maximum width).

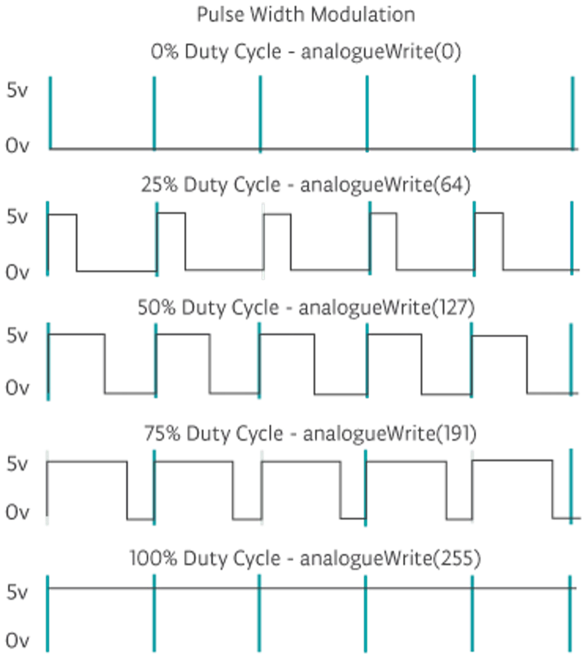
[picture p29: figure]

5.6 Encoder
Magnetic encoders are sensors that can report information about the rotation speed and the spinning direction of the motor when mounted on a moto. The magnetic encoders are composed of a module with two Hall-effect sensors and magnetic discs. As the motor turns, the disc rotates past the sensors. Each time a magnetic pole passes a sensor, the encoder outputs a digital pulse, also called a “tick”. By counting those ticks, the speed of the motor can be determined.

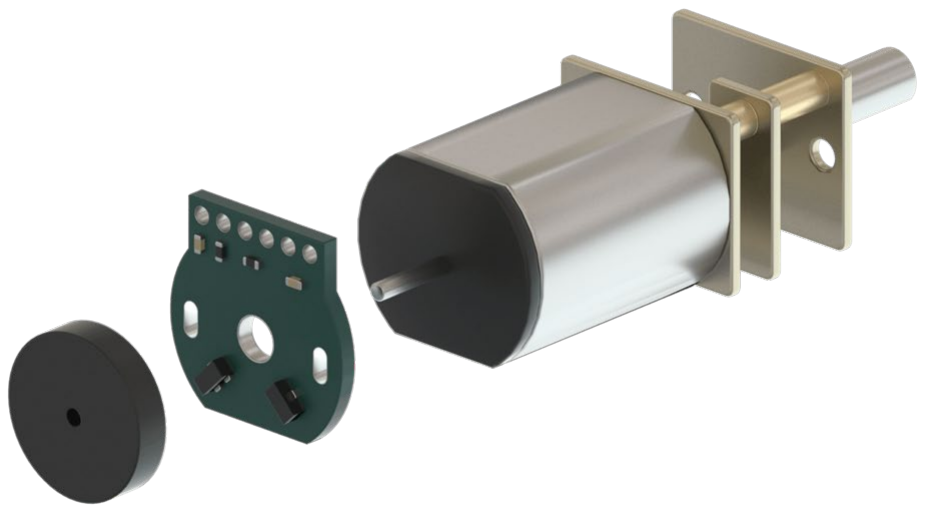
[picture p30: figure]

The encoder has two outputs, one for each Hall effect sensor. The sensors are positioned so that there is a phase of 90 degrees between them. This means that the square wave outputs of the two Hall effect sensors on one encoder are 90 degrees out of phase. This is called a quadrature output.

6. Credits / Resources:
https://www.arrow.com/en/research-and-events/articles/engineering-basics-what-is-a-microcontroller (https://www.arrow.com/en/research-and-events/articles/engineering-basics-what-is-a-microcontroller)
https://www.arduino.cc/
https://www.arduino.cc/reference/en/https://www.arduino.cc/en/Guide/Environmenthttps://aek.arduino.cc/

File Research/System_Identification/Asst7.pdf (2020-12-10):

## Mystery Motor Data Sheet

Motor manufacturers make the motor characteristics below available to you to help you decide which motor to purchase. When you buy a motor second-hand or surplus, you may need to measure these properties yourself. We will use all SI units (which is not the case on most motor data sheets).

Motor Property | Symbol | Value | Units | Comments
Nominal voltage | Vnom | | V | Chosen so the no-load speed is safe for brushes, commutator, and bearings.
Power rating | P | | W | The max continuous mechanical power output at the nominal voltage without overheating.
Max mechanical power | Pmax | | W | The max mechanical power output at the nominal voltage (including short-term operation).
No-load speed | ω0 | | rad/s | Speed when no load and powered by Vnom. Usu- ally given in rpm (revs/min, sometimes m⁻¹
).
No-load current | I0 | | A | Nonzero because of friction torque.
Max continuous current | Ic | | A | Max continuous current without overheating.
Starting current | Is | | A | Same as stall current, Vnom/R.
Max continuous torque | Tc | | Nm | Directly proportional to max continuous current.
Stall torque | Ts | | Nm | Same as starting torque.
Max efficiency | ηmax | | % | Approximately
1 −

qI0
Is

2
, occurring at approx-
| | | | imately 1/7 of stall torque.
Terminal resistance | R | | Ω | May change as brushes slide over commutator segments. Increases with heat.
Terminal inductance | L | | H | Due to the coils.
Electrical time constant | τe | | s | The time for the motor current to reach 63% of its final value. Equal to L/R.
Torque constant | kt | | Nm/A | Also called the motor constant.
Electrical constant | ke | | Vs/rad | Same numerical value as the torque constant (in SI units). Also called voltage or back-emf constant.
Speed constant | ks | | rad/(Vs) | Inverse of electrical constant.
Mechanical time constant | τm | | s | The time for the motor to go from rest to 63% of its final speed under constant voltage.
Rotor inertia | J | | kgm² | Often given in units gcm²
Short-circuit damping | B | | Nms/rad | Not included in some data sheets, but useful for motor braking (and haptics).
Friction | | | | Not included in most data sheets. See explanation.

All of our motor modeling derives from the power equality

IV
|{z}
electrical power in

= T ω
|{z}
mech power out

+ I

2R
|{z}
coil heating

+ I L dI/dt
| | {z | }
charging coils

+ friction losses

and the relation, due to Lorentz’s force law,
T = ktI.

Dividing the power equation by I, and ignoring friction for now, we get the common voltage equation

V = kt ω + IR + L dI/dt,

where it is more common to see kt written as ke. They are equivalent, but in the torque equation this constant converts amps to Newton-meters, and in the voltage equation it converts radians/s to volts.

## Getting to Know Your Brushed DC Motor

Here are some things to try to get to know your motor and encoder:

1. Spin the motor shaft by hand. Get a feel for the rotor inertia and friction.
2. Now short the motor terminals by plugging the wires into the same row of a breadboard. Spin again by hand. Do you notice a difference?
3. Work with a partner. Connect your two motors together so the + terminals of the motors are attached to each other, and the − terminals are attached to each other. (Doesn’t matter which terminal you call + or −. Connect the wires through the breadboard.) No batteries or external power. Now try spinning one of the motor shafts by hand. What do you predict will happen to the other motor, if anything? What actually happens?
4. Try measuring your motor’s resistance using your multimeter. Notice that it varies with the angle of the shaft, and it may not be easy to get a steady reading. What is the minimum value you can get reliably?
5. Attach your motor’s encoder cable to +5 V (red wire) and GND (black) of your nuScope. Attach the other two encoder wires to two of your scope’s digital inputs. Attach one of your motor terminals to channel A on your scope, and the other to scope ground. Spin the shaft by hand and observe the encoder pulses, including their relative phase. Also observe the back-emf on channel A.
6. Now disconnect your two motor terminals from the scope, and instead power your motor using a 6 V battery pack. Your motor’s encoder has 100 lines. Given this, and the rate of the encoder pulses you observe on your scope, calculate the motor’s no-load speed and enter it on your data sheet.
7. Work with a partner. Couple your two motor shafts together using some tubing. Now plug one terminal of one of the motors (we’ll call it the passive motor) into channel A of a scope, and plug the other terminal of the passive motor into GND of the same scope. Now power the other motor (the driving motor) with 6 V so that both motors spin. Measure the speed of the passive motor by looking at its encoder count rate. Also measure its back-emf on channel A. With this information, calculate the passive motor’s electrical constant ke. (Note: You may need to use your multimeter to measure the back-emf, instead of the scope, if the back-emf exceeds the range of the scope.)

You can now continue with the assignment at the end of this document. Some methods for completing the assignment are suggested below.

## Characterizing a Brushed DC Motor

Below are some ideas for characterizing a motor using mostly your nuScope, multimeter, encoder (or any way to measure the motor speed), and resistors and capacitors. There is more than one way to measure most of these motor parameters. Feel free to come up with your own methods.

Nominal voltage This voltage is just a recommendation. Exceeding the nominal voltage is fine, though damage to the brushes and commutator, or to the bearings, is possible at high speeds. Nominal voltage cannot be measured, but a typical no-load speed for a brushed DC motor is between 3000 and 10,000 rpm, so the nominal voltage will usually give a no-load speed in this range. For our data sheet, we’ll use a nominal voltage of 6 V. (The motor is rated for 24 V, but we want to keep current low.)

Power rating It is not easy to come up with thermal ratings without permanently damaging the motor. Assume that the motor coils can dissipate up to 5 W continuously before overheating.

Max mechanical power The max mechanical power occurs at 1
2

Ts and 1
2

ω0. For most motor data sheets, the max mechanical power occurs outside the continuous operation regime.

No-load speed You can determine ω0 by measuring the unloaded motor speed when powered with the nominal voltage. The amount this is less than Vnom/ke can be attributed to friction torque.

No-load current You can determine I0 by using a current-sensing resistor and an oscilloscope/multimeter, or by using a multimeter in current measurement mode. Friction torque is ktI0.

Max continuous current For our motor, assume that the motor coils can dissipate up to 5 W continuously before overheating. Use your estimate of motor resistance to then estimate the max continuous current.

Starting current Starting current is equivalent to stall current. You can estimate this using your estimate of R. Since R may be difficult to measure with a multimeter, you can instead put a current sensing resistor in series with the motor, stall the motor, and measure the current flowing through the motor and resistor by measuring the voltage across the resistor. Make sure your estimate accounts for the voltage drop across the resistor. Alternatively, dispense with the current sensing resistor and use your multimeter in current sensing mode, provided the multimeter can handle the current.

Max continuous torque This is determined by thermal considerations. We will assume that the motor coils can dissipate up to 5 W continuously.

Stall torque This can be obtained from ke and Is.

Max efficiency Efficiency is defined as the power out divided by the power in, T ω/(IV ). The wasted power is due to coil heating and friction losses. Friction torque is proportional to I0, so the smaller I0 is, the more efficient the motor is. Motors are most efficient at converting electrical power to mechanical power at high speeds, or approximately (1/7)Ts.

Terminal resistance You can measure R with a multimeter. The resistance may change as you rotate the shaft by hand, as the brushes move to new positions on the commutator. You should record the minimum resistance you can reliably find. A better choice, however, may be to measure the current when the motor is stalled. See the description of starting current, above.

Terminal inductance There are a number of ways we could measure inductance, for example based on an L/R time constant we can observe with an oscilloscope, or based on the oscillation frequency of an RLC circuit if we add a capacitor. We propose the latter method. (If you’d like to try something else, be our guest, but (1) make sure to document your method, and (2) if you are driving the motor with a current from your nuScope, be sure to use a 1 kΩ resistor in series with the motor, to limit the current the scope has to provide.)
We’ll use the nuScope to generate a 1 kHz square wave to pulse an RLC circuit constructed of the motor, which acts as a resistor and inductor, and an added capacitor. Build the circuit shown below, where a good choice for C may be 0.01 µF or 0.1 µF:

Motor; 1 kHz square wave; scope ch A

Use the nuScope to put a 1 kHz square wave at the point indicated. The 1 kΩ resistor limits the current from the scope. The motor is modeled as a resistor and inductor. (Back-emf will not be an issue, because the motor will not move, as it is being driven with tiny current at high frequency.) Measure the voltage with your nuScope where indicated. You should be able to see a decaying oscillatory response to the square wave transitions when you choose the right V/div and s/div on your scope. Measure the frequency of the oscillatory response. Knowing C and that the natural frequency of an RLC circuit is ωn = 1/

√
LC in rad/s,
estimate L.
Let’s think about why we see this response. Say the input to the circuit has been at 0 V for a long time. Then your scope will also read 0 V. Now the input steps up to 5 V. After some time, in steady state, the capacitor will be an open circuit and the inductor will be a closed circuit (wire), so the voltage on the scope will settle to 5 V × (R/(1000 + R))—the two resistors in the circuit set the final voltage. Right after the voltage step, however, all current goes to charge the capacitor (as the zero current through the inductor cannot change discontinuously). If the inductor continued to enforce zero current, the capacitor would charge to 5 V. As the voltage across the capacitor grows, however, so does voltage across the inductor, and therefore so does the rate of change of current that must flow through the inductor (by the relation VL + VR = VC and the consitutive law VL = L dI/dt). Eventually the integral of this rate of change dictates that all current is redirected to the inductor, and in fact the capacitor will have to provide current to the inductor, discharging itself. As the voltage across the capacitor drops, though, the voltage across the inductor will eventually become negative, and therefore the rate of change of current across the inductor will become negative. And so on, to create the oscillation. If R were large, i.e., the circuit were heavily damped, the oscillation would die quickly, but you should be able to see it.
(Note that you are seeing a damped oscillation, so you are actually measuring a damped natural frequency. But the damping is low if you are seeing at least a couple of cycles of oscillation, so the damped natural frequency is indistinguishable from the undamped natural frequency.)

Electrical time constant The electrical time constant is just L/R.

Torque constant You can measure this by spinning the shaft of the motor, measuring the back-emf at the motor terminals, and measuring the rotation rate using the encoder. If friction losses are negligible, a good approximation is Vnom/ω0. This eliminates the need to spin the motor externally.

Electrical constant Identical to the torque constant. When written in SI units, kt and ke have the same numerical values, but often kt will be given in mNm/A or English units like oz-in/A, and often ke will be given in V/rpm.

Speed constant Just the inverse of the electrical constant.

Mechanical time constant The mechanical time constant is JR/k²
t

, the time it takes the unloaded motor to reach 63% of its final speed under a constant voltage input and in the absence of friction. The time constant can be measured by applying a constant voltage to the motor, measuring the velocity, and determining the time it takes to reach 63% of final speed.

Rotor inertia The rotor inertia can be estimated from measurements of the mechanical time constant, kt ,
and R. Alternatively, a constant current could be applied to the motor and the motor’s position differentiated twice to get acceleration α. Then the inertia can be estimated using the relation J = T /α = ktI/α. Note that constant current/torque/acceleration is not possible for long periods of time.

Short-circuit damping When the terminals of the motor are shorted together, you get a viscous damping torque T opposing the shaft angular velocity ω, satisfying the equation T = −Bω, where B > 0. The damping B can be calculated from the torque constant and terminal resistance.

Friction Friction torque arises from the motor shaft spinning in the bearings, and may depend on external loads. A typical model of friction includes both Coulomb friction and viscous friction, and may be written

Tfric = −b0 sgn(ω) − b1ω,

where b0 is the Coulomb friction torque, indicating that the friction torque opposes the direction of motion (sgn(ω) just returns the sign of ω), and b1 is a viscous friction coefficient.

## ME 333 Introduction to Mechatronics Assignment 7: Characterizing a Brushed DC Motor

Electronic submission due before 12:30 PM Tuesday March 1

1. There are 20 entries on the data sheet on the first page of this document. Let’s assume zero friction, so we ignore the last entry. (We will also assume that the motor coils can dissipate a maximum of 5 W continuously without overheating.) Of the 19 remaining entries, under the assumption of zero friction, how many independent entries are there? That is, what is the minimum number N of entries you need to be able to fill in the rest of the entries? Give a set of N independent entries from which you can derive the other 19 − N dependent entries. For each of the 19 − N dependent entries, give the equation in terms of the N independent entries. For example, Vnom and R will be two of the N independent entries, from which we can calculate the dependent entry Is = Vnom/R.
2. Based on your experiments, create a data sheet with all 20 entries for Vnom = 6 V. For the remaining 19 entries, indicate how you calculated the entry. (Did you do an experiment for it? Did you calculate it from other entries? Or did you do estimate by more than one method to cross-check your answer?) For the friction entry, you can assume Coulomb friction only—the friction torque opposes the rotation direction (b0 6= 0), but is independent of the speed of rotation (b1 = 0). For your measurement of inductance, turn in a screen snap of the scope trace you used to estimate ωn and L, and indicate the value of C that you used.

Note: If there are any entries you are unable to estimate experimentally, simply say so and leave that entry blank.

3. Based on your data sheet, draw the speed-torque curves on the next page, and answer the associated questions.

## Speed-Torque Curves

Draw the speed-torque curve for your motor assuming a nominal voltage of 6 V. Indicate the stall torque and no-load speed. If the motor coils can dissipate a maximum of 5 W continuously before overheating, indicate the continuous operating regime. What is the power rating P for this motor? What is the max mechanical power Pmax?

(Do not do any more experiments for the remainder of this problem; just extrapolate your previous results.) Draw the speed-torque curve for your motor assuming a nominal voltage of 24 V. Indicate the stall torque and no-load speed. If the motor coils can dissipate a maximum of 5 W continuously before overheating, indicate the continuous operating regime. What is the power rating P for this motor? What is the max mechanical power Pmax?

Often DC motors spin at speeds that are too high, and torques that are too low, to be useful. If we put a G = 10, or 10:1, gearhead on the output of our motor, however, the speed of the motor is reduced by a factor of 10 (ωout = ωin/G) and the torque is increased by a factor of 10 (Tout = GTin). Draw the speed-torque curve for the 24 V motor (the previous curve you drew) with a 10:1 gearhead and indicate the no-load speed and stall torque.

Gearheads are not 100% efficient; some power is lost due to friction and impact between gear teeth. Now assume our 10:1 gearhead from the previous example is η = 80% efficient. The relation ωout = ωin/G must be preserved (it’s enforced by the teeth), so we will use the relation Tout = ηGTin, giving Pout = Toutωout = ηTinωin = ηPin. Draw the speed-torque curve for the 24 V motor with an 80% efficient 10:1 gearhead.

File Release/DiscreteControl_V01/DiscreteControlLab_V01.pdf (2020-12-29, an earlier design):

The Iby and Aladar Fleischman Faculty of Engineering Tel Aviv University

# Discrete Control Lab

## 1. Introduction

Modern control systems are realized using a micro controller unit (MCU) and implemented in code. Since an MCU is a discrete system, the control implementation is also a discrete control system. In this experiment, you will get a taste of implementing a simple motor control system using an Arduino development board with the Arduino development environment (IDE).

## 2. System overview

The experiment setup consists of Arduino Uno development board with a carrier shield for motor driver, a DC motor including a gearbox, encoder and a rotation mass. The control is implemented in code using an Arduino development environment in C++. For thorough description of the experiment concepts see literature review chapter.

System components:

- Arduino Uno Micro Controller Unit (MCU): https://store.arduino.cc/arduino-uno-rev3
- Motor Driver Shield (H-bridge): https://www.sparkfun.com/products/14129
- DC Motor including Gear box 1:100: https://www.pololu.com/product/3041
- Magnetic Encoder with 3PPR (Pulses Per Revolution) : https://www.pololu.com/product/3081
- Rotating mass Flywheel:
https://www.pololu.com/product/1420
- 12V Power supply:
- https://www.4project.co.il/product/wall-adapter-power-supply-12v-1a (https://www.4project.co.il/product/wall-adapter-power-supply-12v-1a)

https://www.arduino.cc/en/Main/Software; - 3D Printed Case: https://a360.co/3iXi0aZ

- PC with an Arduino IDE Connected over USB cable:

https://www.4project.co.il/product/a2b-standard-usb-cable-1.8m


## 3. Discrete Control Part 1 – Simulation

Throughout this section we are going to explore the concepts of a DC motor system and learn the implementation of a discrete velocity motor control by employing a simulation in Simulink. We will get familiar with the concepts of a sampled system and its influence on the control performance.

3.1 Matlab Simulation review, Open loop.
Start by opening Simulink model: dcMotorControlSim.slx, the model contains open and closed loop implementation of a motor velocity control. The model relies on an initialization script dcMotorControlInit.m, which sets the system sample time variable. Make sure it is present in the work folder which contains the simulation model.

Run the model in open loop with various motor command values. You may change the stop time of the simulation to inf and change the values through the slider while the simulation is running. Note the motor RPM calculation as measured by the Encoder compared to the Actual RPM.


Change the system’s sampleTime variable and note the influence on the Encoder RPM calculation. You can update the variable through the Command window in Matlab.

Open loop with motor command at 0.25 Simulation sampleTime 0.01 sec


Open loop with motor command at 0.25 Simulation SampleTime 0.1 sec

Open the simulation subsystem named Motor System and review how it is implemented and it`s subsystems. Explain how the encoder works and how the motor velocity is calculated.

Hint: it is implemented at dcMotorControlSim/Motor System/Hall Effect Sensor/Decoder/Pulse decode.

3.2 Close loop proportional control
For this part of the experiment we will consider the system as a black box -without a known continuous model and learn how to manually tune the controller to achieve the desired system response. First route the model switches to use the signals from the PID controller output, and for the feedback the Ideal RPM value, as depicted in the figure below. Make sure to change back the simulation sample time to 0.01 sec.


For this simulation a discrete implementation of the PID controller is used (the block PID(z) ). Open the PID block and set it to a proportional gain only.

dcMotorContrlSim.slx, set for PID feedback

Evaluating the initial value for the proportional gain: at the previous section, we have used various motor commands values, which resulted in various motor velocities. From the model review section, you may have noticed that the PWM command is scaled by a value of 0 to 1. Zero for 0-duty cycle – Motor is off and one for 100% duty cycle – Motor works in full power. For a 0.25 value, we got a response of approximately 80 RPM. Meaning that a rational starting value for a step response of 100RPM will be at the proximity of 0.01 gain. The reasoning is that for a starting error of 100 we will get a starting motor command of 1 which is equivalent to 100% duty cycle. Run the simulation with various gains and review the response.


Close loop response Ideal RPM feedback, kP=0.01 SampleTime=0.01

Choose a proper response gain which results in a slight overshoot and switch to the Encoder feedback. What have happened? The system has lost stability. Perform the experiment with various gains and review the system response you get. Change the sample time and see what happens, run the experiment at different settings (10 gains values and 5 sampleTime values ranging at 0.1-0.001sec) make conclusion for best gains at various sample rate.


Because the experiment is based on discrete system implementation and uses an encoder, the system under study can no longer considered to be linear. Write down several rules of thumb concluded from the experiments for a proper proportional gain value.

- Consider the rise time as a function of the control loop frequency (sampleTime).
- Consider the Encoder resolution influence.

Ideal fedback vs Encoder feedback. kP=0.05, sampleTime=0.01

3.3 Close loop PID tuning
After setting a proper response with a proportional gain controller, our next objective is to improve the response by adding the integral and deferential component of the PID controller. Set the model to encoder feedback and sampleTime variable of 0.01sec.

First, we would like to eliminate the steady state error. Begin with adding an integral term and scale the proportional gain. Gradually increase the gain and review the system response. If the system loses stability, you may consider to slightly reduce the proportional gain (explain this phenomena). Tune the system until you get a rise time of 0.1 sec, overshoot of up to 10% and settling time of 0.2 sec.


The differential gain isn`t mandatory for a velocity control loop of a DC motor but you may consider adding it to slightly reduce the system overshoot. A good starting point will be at the range of kp*sampleTime.

You may have noticed that the controller is lacking stability at low velocity, which isn`t an issue when using an ideal feedback. In the final report, discuss the reasons for this phenomenon. For the actual experiment we will be using a slightly improved method for velocity estimation based on the encoder feedback, therefore the simulation will be more robust at low velocities.

3.4 PID code implementation
Open Simulink model dcMotorControlSimPIDcode.slx. Note that it has a Matlab function for implementing the PID control in code. Route the system Control command to the Matlab PID function. It has the implementation of proportional gain only. Review the code and complete it for the full PID implementation (add the integral and derivative terms). Compare the response between the Simulink block and the code implementation that you have just completed for identical PID values.


function motorCMD = PID(dt,cEr)
% persistant variables persist between function calls. similar to % static variable declaration in c
persistent lEr cdEr ciEr;
if isempty(lEr) %initialize variables for first run of the code. lEr = 0; % previous error initialization
cdEr = 0; % differantional error initialization
ciEr = 0; % integral error initialization
end
% control coeficients
kp = 0.025;

% clip integrator error
if (ciEr > 10)
ciEr = 10;
elseif (ciEr < -10)
ciEr = -10;
end

% update control command
motorCMD = kp*cEr;

% clip motor command
if (motorCMD > 1)
motorCMD = 1;
elseif (motorCMD < -1)
motorCMD = -1;
end

% update last error variable before next iteration lEr = cEr;

## 4. Discrete Control Part 2 – Hardware

In this section we will implement the control laws using the Arduino IDE (Integrated Development Environment) in C++ and monitor its response by employing the embedded tool of the IDE. Since most of the modern control systems use a micro controller for motor control this experiment will be a good peek into the actual implementations of the learned theories during the classes.
4.1 Getting started with Arduino / Arduino IDE
Open Arduino IDE, Either use the desktop icon, or search for the application.


Connect the USB cable to the ArduMotoControl Box. Since the micro controller implement the last code that has been uploaded, you will see the motor spinning upon voltage application. Make sure that the 12V power plug is also connected. When you finish working with the setup, disconnect the power supply and the USB cable.


We will begin by opening the first task and uploading the code to the micro controller. Select: File→Open Navigate to ArduMotorControlEx1.ino and open it.

Connect to the Arduino Uno micro controller and make sure the correct port is selected. The COM number may change between computers.

- Select: Tools→Board→Arduino Uno,
- Select: Tools→Port→COMX (Arduino Uno),

Upload the example to the micro controller by pressing upload button→. If everything is successful than you should see the “Done uploading” message and the motor will start spinning with a Sine Profile.


View the System response using the Serial Plotter tool. Make sure the baud rate is set to 115200 otherwise you get gibberish on the screen instead of the desired data. If everything has started correctly you will see the legend of the data on top of the graph, if it is mixed due to incorrect baud rate or some other start up issue you may reopen the Serial Plotter. It will reset the controller and start correctly.

- Tools→ Serial Plotter

Sometimes during the lab you will be required to record a series of data, for that we will use the Serial Monitor tool. Each time you open the Serial Monitor or the Serial Plotter tool it will reset the micro controller and restart the latest code uploaded to it. When you open the Serial Monitor you will be able to see the streamed values, make sure the baud rate is correct and in order to make a recording deselect the Auto-scroll feature. Select the data set by pressing CTRL+A and CTRL+C, Past the data set into a text file you have created on the pc.

- Tools→ Serial Monitor

You may notice that the recorded data has unfished data at the button of the data set and some values prior the variable names, which are of a previous session (prior reopening the Serial Monitoring tool). In order to make it easier to import the data into Matlab we will preprocess the data set by deleting all the values prior the variable names and the last unfinished line.


At this point importing the data into Matlab is easy using the Matlab Import Data tool. Press the Import Data option select the processed file, make sure the Comma separating is selected and import the samples to the workspace. To fast preview the recorded samples use the Matlab stacked plot option. Right click on the data set in Matlab select Plot Catalog and choose the stacked plot option.

4.2 Code Review
The Experiment is implemented in C++ in order to handle the control section we will review the general approach for the code. When opening the ArduMotorControlEx1 you may have noticed the added files ArduMotoControl.cpp and ArduMotoControl.h those are the library files for the experiment and they have the implementation of the functions available at the main file ArduMotorControlEx1 including the motor driver handling and the encoder reading. You may review them and the comments for each function but for the experiment we will focus at the code in the main file.

The file Starts with the #include line for the library following some variables and function declaration.

- DT_Control_Millis – Sets the control interval for the experiment similar to the simulation. Take care not to exceed the recommended settings as not to overload the CPU. (Nothing will break but the controller will lose its stability)
- motorRPMdt – Is a global variable for the motor velocity based on the time interval between encoder pulses.
- motorRPMPulses – Is a global variable for the motor velocity based on the number of pulses occurred between the calls of the readRPMEncoder() function
- MotorControlLoop – Is a function which is called every controlled interval set by the DT_Control_Millis.
- MotorControl – Is the actual function for the Control implementation called inside the MotorControlLoop function.

Note the sections which start and end with the comment Student Code / Student Function, they indicate the sections which are available for modification so as not to harm the general flow of the rest of the code.


4.3 Open loop velocity response & Encoder readings
For this section we will evaluate the system response and understand the limitation of working with a cheap encoders, Start by Opening the ArduMotorControlEx2.ino sketch in the Arduino environment. Review the code and find the Open loop command inside the MotorControlLoop() function. We will work with a ramp command and step command function which are implemented in the library, the input to the function is the time period and the output is a command in the range of [0..1]. Verify that the StepCMD() function is uncommented with a gain of 0.5 and the RampCMD is commented and upload the code. Open the Serial Plotter and view the system response. The plot contains the desired command, the velocity measurement using the two approaches, time between encoder pulses, and number of pulses per function call RPMdt, RPMPulses.


Change the command to the rampCMD by uncommenting the RampCMD function and commenting the StepCMD function. Upload the updated code to the micro controller and view the response using the Serial Plotter.


Modify the code by changing the gains and the time period generating various commands and view the responses you get. In addition, change the control frequency by modifying the value of DT_CONTROL_MILLIS.

- What is the minimal command for the motor to start moving?
- What is the maximum velocity?
- What can you say about the two methods for velocity measurements? Which is better at high speeds and which for lower speeds, how the control frequency influences the results?

In the final report:

Prepare a recording for analysis in Matlab of a ramp response with a period of 5 seconds, and gain of 0.25, at two control periods, 10ms and 100 ms. Generate plots comparing the measured RPM of both methods.

- A plot containing RPMPulses at the two measured control intervals
- A plot containing the difference between RPMPulses and RPMdt as a function of the motor command for both control intervals.

Settings:

float motorCMD = 0.25 * RampCMD(5);

#define DT_CONTROL_MILLIS 100

Prepare a recording of a step response at a gain of 0.25 and period of 2 seconds. Plot the response in Matlab and mark the rise time of the system.

Settings:

float motorCMD = 0.25 * StepCMD(2);

#define DT_CONTROL_MILLIS 2

4.4 Close loop proportional velocity control
For this section we will implement a simple proportional control command and tune it`s gain. Start by Opening the ArduMotorControlEx3.ino sketch in the Arduino environment. Review the code and find the MotorControl() function. Understand the controller implementation and start with a logical value for the proportional gain – Remember the concepts described at Part 1 - Simulation.

Run a step response of 100RPM with the selected gain and view the response using the Serial Plotter tool. Set the control interval value at 10 milliseconds.

float desiredCMD = 100 * StepCMD(2);

#define DT_CONTROL_MILLIS 10

Change the DT_CONTROL_MILLIS value to 50 and see what happens. Explain the behavior and adjust the gains until you reach a stability. Find the stable gains for DT_CONTROL_MILLIS of 10,25,50 milliseconds. Record each of the responses you get with the final coefficients for each of the control interval for later analysis in Matlab.

In the final report generate a plot containing the 3 step responses generated previously and determine the rise time for each.

Up until now we have tested the proportional gain for a specific velocity of 100RPM, in order to understand the potential stability for various speeds we will use the rampCMD() function. Run a ramp response at 100RPM with 10 milliseconds control interval. With the stable gain found for this control interval.

float desiredCMD = 100 * RampCMD(2);

#define DT_CONTROL_MILLIS 10

From the open loop experiments we have seen that the encoder resolution is far from perfect at the lower velocities. The ramp function helps identify those issue and will allow us to easily tune the gain to meet stability for the desired control range.

Adjust the proportional gain value until a steady response is achieved for the ramp command similar to the plot below. We will be using this value as a starting point for the PID controller next section.

4.5 Close loop PID velocity control
Open the ArduMotorControlEx4.ino sketch in the Arduino environment. Review the code and find the MotorControl() function. Understand the PID controller implementation and start with a logical value for the integral gain – Remember the concepts described at Part 1 - Simulation. Tune the value until a slight overshoot is achieved for a step response of 100RPM and control interval of 10 milliseconds. Record the response for later analysis in matlab.

In the final report calculate the rise time overshoot and settling time of the step response.


Run the ramp Response with the same values. Record the response and in the final report evaluate the instability point. What happens to the encoder values around this point? Compare this point`s motor command to the minimal command needed to start the motor spinning found in the open loop experiment, write your conclusions.


Usually the differential gain isn`t required for the velocity control loop of a dc motor, and at the current example it has a very simplified implementation as such adding it will mainly interfere with the motor control implementation. But in order to understand the concept and the simplified implementation we will run a simple example. Start by setting the differential gain to a logical value using the concepts described at Part 1 – Simulation. Increase the value slightly until it`s influence will be noticed but without losing stability.

In the final report record the results and generate a plot in Matlab marking its influence. Suggest a better implementation of a differential element. Hint – overcoming the error of a numerical differentiation.


4.6 Control loop frequency influence on control performance
For this section we will use the PI coefficients found at the previous section with the differential gain set to zero. (PI Controller). Run a series of step responses at
100RPM at various Control intervals DT_CONTROL_MILLIS. Start with 10ms and increase the value until you lose stability.


Record the experiment with 3 settings of control interval, 10ms last stable value and a middle value.

In the final report generate plots in Matlab marking the rise time and the settling time. Compare the values to the control interval. Write you conclusions regarding suggested control loop frequency.

4.7 (Bonus) Comparison between simulation and actual setup
Run the simulation with a PI controller with the gains found for the hardware setup at a 10ms control interval. Generate a Matlab plot comparing the step response of the simulation and the hardware. The simulation is modeled based on the theoretical parameters of the hardware model, suggest a method to improve the simulation model to meet the actual hardware.

## 5. Literature

5.1 Micro Controller Unit (MCU)
A microcontroller (sometimes called an MCU or Microcontroller Unit) is a single Integrated Circuit (IC) that is typically used for a specific application and designed to implement certain tasks. Products and devices that must be automatically controlled in certain situations, like appliances, power tools, automobile engine control systems, and computers are great examples, but microcontrollers reach much further than just these applications.

Essentially, a microcontroller gathers input, processes this information, and outputs a certain action based on the information gathered. Microcontrollers usually operate at lower speeds, around the 1MHz to 200 MHz range, and need to be designed to consume less power because they are embedded inside other devices that can have greater power consumptions in other areas.

A microcontroller can be seen as a small computer, and this is because of the essential components inside of it; the Central Processing Unit (CPU), the Random-Access Memory (RAM), the Flash Memory, the Serial Bus Interface, the Input/Output Ports (I/O Ports), and in many cases, the Electrical Erasable Programmable Read-Only Memory (EEPROM).


Figure: Parts of a microcontroller. (Source: Max Embedded)

5.2 Arduino Development Board and Environment
Arduino is an open-source electronics platform based on easy-to-use hardware and software. Arduino boards can read inputs, amount of light on a sensor, a press on a button, or the arrival of a Twitter message and turn this into an output, for example, activating a motor, turning on an LED or publishing something online. You can tell your board what to do by sending a set of instructions to the microcontroller on the board. To do this use the Arduino programming language and the Arduino Software (IDE).

Arduino Uno is a microcontroller board based on the ATmega328P . It has 14 digital input/output pins (of which 6 can be used as PWM outputs), 6 analog inputs, a 16 MHz ceramic resonator, a USB connection, a power jack, an ICSP header and a reset button.

Microcontroller | ATmega328P (http://ww1.microchip.com/downloads/en/DeviceDoc/ATmega48A-PA-88A-PA-168A-PA-328-P-DS-DS40002061A.pdf)
Operating Voltage | 5V
Input Voltage (recommended) | 7-12V
Input Voltage (limit) | 6-20V
Digital I/O Pins | 14 (of which 6 provide PWM output)
PWM Digital I/O Pins | 6
Analog Input Pins | 6
DC Current per I/O Pin | 20 mA
DC Current for 3.3V Pin | 50 mA
Flash Memory | 32 KB (ATmega328P) of which 0.5 KB used by bootloader
SRAM | 2 KB (ATmega328P)
EEPROM | 1 KB (ATmega328P)
Clock Speed | 16 MHz

The Arduino environment (IDE) has an extensive support for various micro controllers and includes a core library, which simplifies the programming of microcontrollers.


An introduction to the programming environment is available at

https://www.arduino.cc/en/Guide/Environment

The core function and variables descriptions are available at https://www.arduino.cc/reference/en/

5.3 DC Motor
A DC (Direct Current) motor is a type of motor that will cause the motor shaft to rotate around its longitudinal axis when applying an electric current between its terminal pins. Thus, the DC motor is a type of actuator that transforms electrical current into rotational motion.

There are two parts inside a motor: the rotor (the shaft is part of this) and the stator. Looking at the cross-section of a motor, you can see that the rotor is the moving part and the stator is the static part. The stator and the rotor use both permanent magnets and electromagnets. Depending on the type of motor, the stator can be a permanent magnet while the rotor is an electromagnet, or vice-versa. Turning on the electromagnet creates attraction and repulsion forces that make the motor spin.

The DC motor spins when we apply DC voltage through its two terminal pins. We can vary the speed of the motor by changing the voltage level. Motors can run in both directions just by reversing the direction of the current.

5.4 Motor Driver H-Bridge
Most electric motors need a higher voltage than can be provided by a microcontroller. To control a DC motor from a microcontroller, you’ll need to use a driver. This can be a transistor, a relay or an H-Bridge. The Arduino Motor Carrier uses H-Bridges to drive the DC motors.

The H-Bridge is an electronic circuit that contains four transistors arranged so that the current can be driven to control the direction of the spin and the angular speed. There is a more in-depth explanation of the H-Bridge in section 3.1.4. It is common practice to use PWM (Pulse Width Modulation) signals to control the speed of a motor instead of providing analog voltages.

With the Arduino IDE, if you want to just turn a DC motor on and off, you can use a digitalWrite command with HIGH for ON and LOW for OFF. If you instead want to modify the speed of the motor, you can use the analogWrite command and one of the PWM pins.
5.5PWM
Pulse Width Modulation, or PWM, is a digital modulation technique commonly used to control the power supplied to electrical devices, like motors. The modulation technique consists of changing the width of a periodic signal’s pulse. The width of the pulse is referred to as the duty-cycle and goes from 0% (minimum width) to 100% (maximum width).


5.6 Encoder
Magnetic encoders are sensors that can report information about the rotation speed and the spinning direction of the motor when mounted on a moto. The magnetic encoders are composed of a module with two Hall-effect sensors and magnetic discs. As the motor turns, the disc rotates past the sensors. Each time a magnetic pole passes a sensor, the encoder outputs a digital pulse, also called a “tick”. By counting those ticks, the speed of the motor can be determined.


The encoder has two outputs, one for each Hall effect sensor. The sensors are positioned so that there is a phase of 90 degrees between them. This means that the square wave outputs of the two Hall effect sensors on one encoder are 90 degrees out of phase. This is called a quadrature output.

6. Credits / Resources:
https://www.arrow.com/en/research-and-events/articles/engineering-basics-what-is-a-microcontroller (https://www.arrow.com/en/research-and-events/articles/engineering-basics-what-is-a-microcontroller)

https://www.arduino.cc/

https://www.arduino.cc/reference/en/

https://www.arduino.cc/en/Guide/Environment

https://aek.arduino.cc/

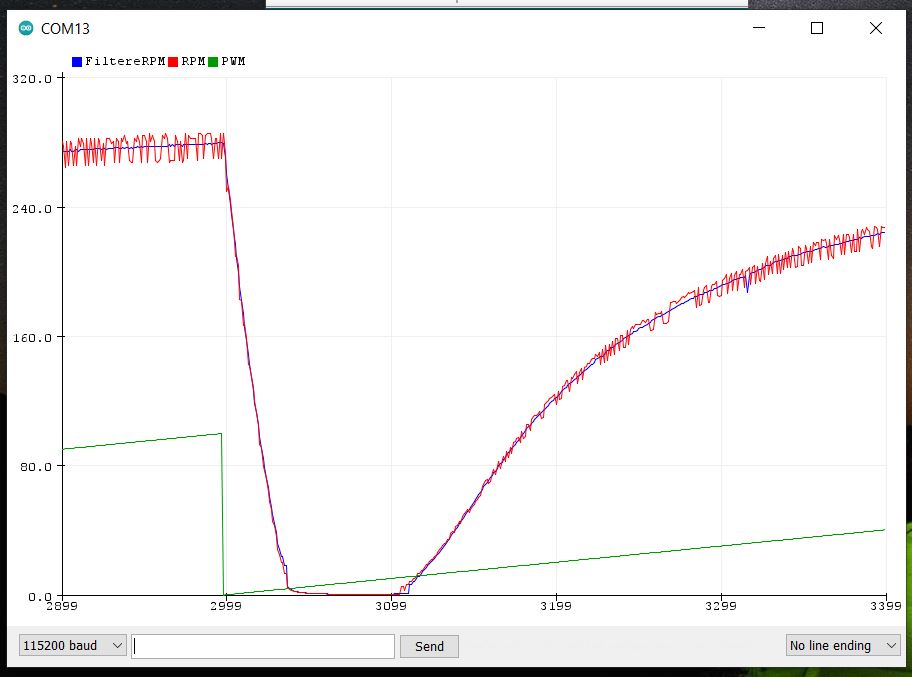
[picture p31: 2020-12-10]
Photos/RPM.JPG

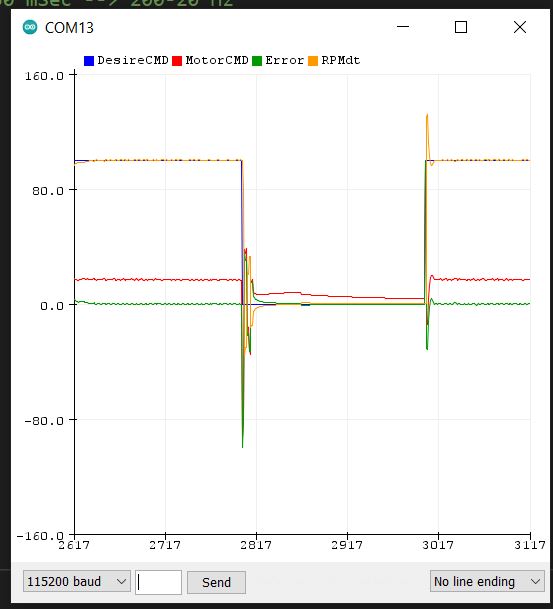
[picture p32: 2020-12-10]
Photos/PI_Controller_Smooth.JPG

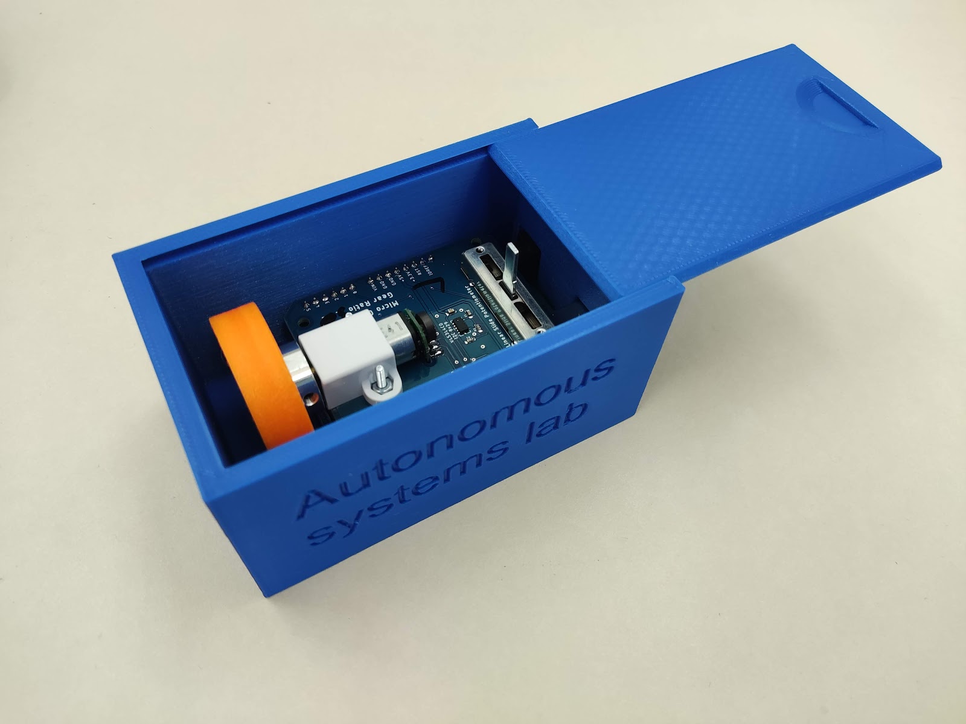
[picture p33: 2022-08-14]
Photos/TAU-ARD Kit_2.jpg

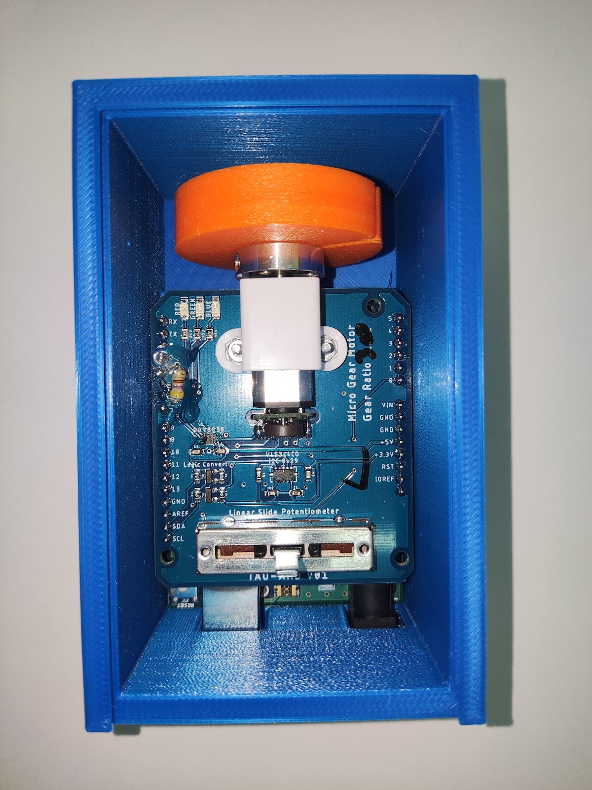
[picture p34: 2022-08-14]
Photos/TAU-ARD Kit_TOP.jpg

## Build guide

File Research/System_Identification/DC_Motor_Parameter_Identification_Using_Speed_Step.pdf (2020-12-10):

Hindawi Publishing Corporation Modelling and Simulation in Engineering Volume 2012, Article ID 189757, 5 pages doi:10.1155/2012/189757

# Research Article DC Motor Parameter Identification Using Speed Step Responses

### Wei Wu

Flight Control and Navigation Group, Rockwell Collins, Warrenton, VA 20187, USA

Correspondence should be addressed to Wei Wu, wu esi@yahoo.com

Received 8 April 2012; Revised 31 August 2012; Accepted 3 September 2012

Academic Editor: F. Gao

Copyright © 2012 Wei Wu. This is an open access article distributed under the Creative Commons Attribution License, which permits unrestricted use, distribution, and reproduction in any medium, provided the original work is properly cited.

Based on the DC motor speed response measurement under a step voltage input, important motor parameters such as the electrical time constant, the mechanical time constant, and the friction can be estimated. A power series expansion of the motor speed response is presented, whose coefficients are related to the motor parameters. These coefficients can be easily computed using existing curve fitting methods. Experimental results are presented to demonstrate the application of this approach. In these experiments, the approach was readily implemented and gave more accurate estimates than conventional methods.

### 1. Introduction

DC motors have wide applications in industrial control systems because they are easy to control and model. For analytical control system design and optimization, sometimes a precise model of the DC motor used in a control system may be needed. In this case, the values for reference of the motor parameters given in the motor specifications, usually provided by the motor manufacturer, may not be considered adequate, especially for cheaper DC motors which tend to have relatively large tolerances in their electrical and mechanical parameters. General system identification methods [1–4] can be applied to DC motor model identification. In particular, various methods have been applied to DC motor parameter identification; that is, [5, 6] used the algebraic identification method, [7] used the recursive least square method,
[8] applied the inverse theory, [9] used the least square method, and [10] applied the moments method. Identified DC motor models are often subsequently used for controller design and/or optimization, for example, [6, 9, 11].
Without expensive testing apparatus and a long testing cycle, a quick and effective system identification approach based on the motor input and output is desirable and valuable, especially for the field applications and quick controller prototyping. In this paper, a DC motor parameter identification approach based on the Taylor series expansion of the motor speed response under a constant voltage input is presented. The relationships between the motor parameters and the coefficients of the Taylor series are established. In the implementation, the motor speed response under a constant voltage is sampled, then fit the samples to obtain the coefficients of power terms in the Taylor series. Then, the DC motor mechanical and electrical time constants, back-EMF, and the friction can be computed using these coefficients. With the knowledge of these parameters, a precise motor model is obtained for the subsequent controller design.
For application point of view, this approach requires only a speed/position sensor, such as an optical encoder, and a voltage power supply, no current measurement is needed and the motor is run in open loop; thus it is practical and cost effective. The curve fitting can be performed using many existing methods, such as the least square method, and these optimization methods are widely available in commercial computing packages such as Matlab and LabVIEW.

### 2. Main Results

Consider the following DC motor governing equations:

L di
dt + iR + kbω = V,

J

dω
dt = kti + Td,

(1)

where ω is the motor speed, V is the motor terminal voltage, i is the winding current, kb is the back-EMF constant of the motor, kt is the torque constant, R is the terminal resistance,

2 | Modelling and Simulation in Engineering

L is the terminal inductance, J is the motor and load inertia,
and Td is the disturbance torque. Td is a combination of the
cogging torque, Tcog, the kinetic friction, Tf , and the viscous friction (viscous damping force):
Td = Tcog + Tf + cω˙ , | (2)

where c is the damping coefficient. According to (1), the velocity response in the Laplace domain is

ω(s) = | 1/kb
tmtes2 + tms +1

V(s) + (1/J)tm(tes +1)
tmtes2 + tms +1

Td(s), (3)

where te = L/R is the electrical time constant, tm = RJ/ktkb is the mechanical time constant, and s is the Laplace variable. Based on these equations, we would like to know tm, te, Td, J, and so forth, by measuring the velocity response under a known, controlled voltage input. In this paper, we consider two application situations: the first situation is that the disturbance torque is negligible, while in the second one, the disturbance needs to be considered.

2.1. Estimation without the Disturbance Torque. When the voltage speed response dominates; for example, the input voltage is large, we can ignore the disturbance torque in the speed response see (3). In this case, we can consider the following DC motor model:

ω(s)

V(s) = | 1/kb
tmtes2 + tms +1 . | (4)

The transfer function can be factorized into

ω(s)
V(s) = | 1/kb
tmte(s + a)(s + b)
, | (5)

where

a, b = ¹ ∓ -

1 − 4te/tm
2te
. | (6)

Assumption. It is assumed here that there are two distinct real poles; that is, tm > 4te.
For a constant voltage input V(s) = V0/s, the speed response is
ω(s) = | V0/kb

tmtes(s + a)(s + b) = α1
s

+

α2
s + a

+

α3
s + b

, (7)

where

α1 = V0
kb

, α2 = V0
kb

b
a − b

, α3 = V0
kb

a
b − a

. (8)

Consider the three terms in the step response one at a time. α1/s is a step function in the time domain; both α2/(s + a) and α1/(s + b) are exponential functions in the time domain and can be expanded using the Taylor series. Expanding the term α2/(s + a), we get

V0
kb

b
a − b
1 − at +

1
2

a2t

2 − ¹
6

a3t

3 + ···
. (9)

Expanding the term α3/(s + b), we get

V0
kb

a
b − a
1 − bt +

1
2

b2t

2 − ¹
6

b3t

3 + ···
. (10)

Combining the three terms together, we have the total speed response:

ω(t) = V0
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
24β2t

4 + ···
, (11)

where β0 = ab, β1 =−ab(a + b), and β2 = ab(a2 + ab + b2). According to (6),

ab = 1
tmte

, a + b = 1
te
. | (12)

Thus, we have

# tm =−β1

β²
0

# , te =−β0

β1

. | (13)

The above equation allows us to calculate the mechanical and electrical time constants tm and te using the coefficients of the power series in (11). These coefficients can be obtained by curve fitting the motor speed step response data using power functions.

2.2. Estimation with the Disturbance Torque. Consider that the disturbance torque in the DC motor is not negligible. The disturbance transfer function is

ω(s)

Td(s) = ⁽¹/J)tm(tes +1)
tmtes2 + tms +1 . | (14)

Disturbance torque generally consists of the cogging torque and the friction torque. The cogging torque is quite complicated and is not addressed here. Both the kinetic and viscous frictions are considered and are assumed to be constant on average under a constant motor speed.
Given a constant motor terminal voltage V(s) = V0/s and the constant disturbance (ignore the cogging torque or consider the average cogging torque effect on speed over one revolution is zero) Td(s) = T0/s, the speed response is
ω(s) = | 1/kb
tmtes2 + tms +1

V0
s

+ (1/J)tm(tes +1)
tmtes2 + tms +1

T0
s . (15)

As in the previous section, applying the partial fraction expansion of the step response in the Laplace domain, then expanding the exponential terms in the time domain using the Taylor series, we obtain the total step response in the time domain:

ω(t) = β0t + β1t

2 − β2t

3 + β3t

4 −··· . (16)

Based on these coefficients, we have

ab = ¹⁸β²
2 − 24β3β1
3β0β2 +2β²
1

,

a + b = ⁶β2 − β0ab
2β1

,

(17)

and another equation for a + b:

a + b = ¹²β3 + β1ab
2β2
. | (18)

Modelling and Simulation in Engineering | 3

Table 1: RK370CA parameter values.

Parameter | Value | Unit
Terminal resistance | 17 ± 15% | Ω
Terminal inductance | N/A | Henry
Torque constant | 18.3 ± 18% | mNm/A
Mass moment of inertia | 9.0 | gcm²
Counter-electromotive force | 0.0233 | volt/(rad/sec)

Then, we can express the motor parameters as

tm = a + b
| ab ,

te = 1
| a + b

,

T0
| J = β0,

kb = ab
2β1
| V0.

(19)

In practice, fit the measured motor speed step response using power functions according to (16); then calculate the motor parameters using (19).

Remark 1. Another relationship useful for checking the algorithm is based on the steady-state response of (15), expressed by the following equation:

V0
kb
+ β0tm = ωss, | (20)

where β0 = T0/J and ωss is the motor steady-state angular speed.

### 3. Implementation and Results

The proposed approaches were first applied to a Mabuchi RK370CA motor, then a Mabuchi FC130 motor. To implement the algorithms, a LabVIEW program was created to interface a pulse width modulated (PWM) motor drive and an optical encoder with quadrature digital outputs mounted on the motor shaft. The determinism of the sample time was assured by the LabVIEW real-time module. And, a national instrument (NI) LabVIEW FPGA (field programmable gate array) card was utilized to process the digital quadrature encoder signals to obtain the motor speed and to control the motor PWM drive.
Values of the motor parameters given in the motor specifications for reference are presented in Table 1.
Note that the Back-EMF and torque constant are not equal (although it should be theoretically). Inductance value is not given and was measured as 20.25 Henry. The resistance was measured as 16.4 Ω. Thus we calculated te = L/R = 0.00122 sec.
First, apply the algorithm for no-disturbance torque. To apply this algorithm, the speed response part due to the voltage input is assumed to dominate. To meet this condition,

Table 2: RK370CA test results.

Parameter w/o dist.
20 v

w/dist.
| | 2 v/10 v | Spec. (meas.) | Unit
kt | 0.0238 | 0.0207/0.0169 0.0183 ± 18% | Nm/A
tm | 0.0407 | 0.0211/0.0203 | 0.0359 | sec
te | 0.00554 | 0.00122/0.00134 | (0.00122) | sec
T0/J | N/A | 10.551/115.758 | N/A | Nm/kgm²

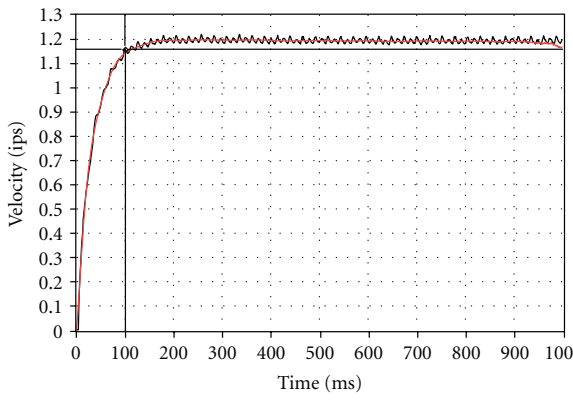
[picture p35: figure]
Time (ms); Velocity (ips)

0 | 100 200 300 400 500 600 700 800 900 1000

Figure 1: Approach w/consideration of disturbance under 2 volt input: black, measurement: red, power series fitted.

for example, the speed variation at the steady-state is small compared to the steady-state speed, we send a large voltage to the motor drive, V = 20 volt. Next, we apply the approach for disturbance torque. The disturbances, that is, friction, effects on the speed response are significant when the input voltage is small. To demonstrate the effectiveness of the algorithm, we sent two voltages, 2 volt and 10 volt, to the motor. Driving the motor at two different voltage levels can demonstrate that the viscous friction varies with the speed, also can allow us to calculate the viscous damping coefficient.
Usually te is very small compared to tm a good estimate of both te and tm at the same time is difficult. Because tm is usually much larger than te, tm and te were estimated separately using different data collected with different sample rates and different time durations. For estimating tm, the motor speed in both the transient phase and the steady-state was sampled at 1 kHz for one second; for estimating te, the motor speed in the transient phase was sampled at 8 kHz for 200 msec. In each test, the motor was driven multiple times and parameter estimates were averaged.
Results are summarized in Table 2. Column two gives the values estimated using the algorithm for no disturbance, and column three gives the values obtained using the algorithm considering disturbance; values in the fourth column are computed using values from Table 1. Note that R = 17Ω, J = 9 gcm², kb = 0.0233 volt/(rad/sec), and kt = 0.0183 Nm/A are used to calculate tm in the fourth column of the table. According to Table 2, the estimates of kt, tm, and te are in good agreement with those given by the motor specifications. Time responses sampled at 1 kHz for 1 s are given in Figures 1, 2 and 3. In these figures, red curves represent the power series, n
| i=1 xiti
, resulting from curve fitting the motor

4 | Modelling and Simulation in Engineering

Table 3: FC130 test results.

Parameter | w/dist. | Spec. | Unit
kt | 0.0137 | 0.0127 ± 10% | Nm/A
tm | 0.0208 | 0.024 | sec
te | 0.251 | 0.214 | msec

speed responses. Comparing these figures, it is obvious that the approach with disturbance consideration approximates the measurements much better, because of the existence of the linear term, β0t, in the power series due to the presence of the constant disturbance in the motor.
To further demonstrate the effectiveness of the proposed algorithms, we compared them to conventional identification approaches. First, we drove the motor using random voltage input (10 volts maximum) and measured the motor speed at a sampling rate of 10 kHz. Then, the motor/drive frequency response function was calculated through spectral analysis. Based on the calculated frequency response data, we used Matlab system identification toolbox to identify a second-order model. Various methods, that is, subspace approach in the system identification toolbox, were tried and compared. The best model found was
| T(s) = | 9078
| | s2 + 334.6s + 18860 . | (21)

Using the model coefficients, we get

| tm = 0.0177 sec, | te = 3 msec,
kt = 0.031 volts/(rad/sec). | (22)

These estimates are bad, especially the electrical time constant te due to the very small time scale as alluded to earlier.

Remark 2. T0/J may be used to calculate the friction (both kinetic and viscous) if J is known. First, calculate the viscous friction coefficient c = (T1 − T0)/(ω1 − ω0). Then, calculate the dynamic friction, Tf = T0 − cω0. For example, ω0 = 1.21 ips under 2 volt, ω1 = 6.274 ips under 10 volt, J = 9.0 gcm², and it renders c = 0.0187 mNm/ips.

Remark 3. The number of terms in the power series included for fitting the data was determined through trial and error. When disturbance was not considered, twenty-five terms were included; when disturbance was considered, including forty terms gave the best results. Since the coefficients were calculated using the polynomial curve fitting function from the math library provided inside LabVIEW, it was not difficult and time consuming to try different number of terms. Including more terms does not necessarily improve the parameter estimation accuracy.
A Mabuchi FC130 motor was tested as well. It is a smaller motor compared to RK370. Good results were obtained again this time; see Table 3. Note the very small te in this small motor. Algorithm considering disturbance torque was applied. In the testing, 10 volts was used as the motor drive input. For tm estimation, the speed response was sampled at 1000 Hz for 500 samples, while for te estimation, it was sampled at 6000 Hz for 850 samples.

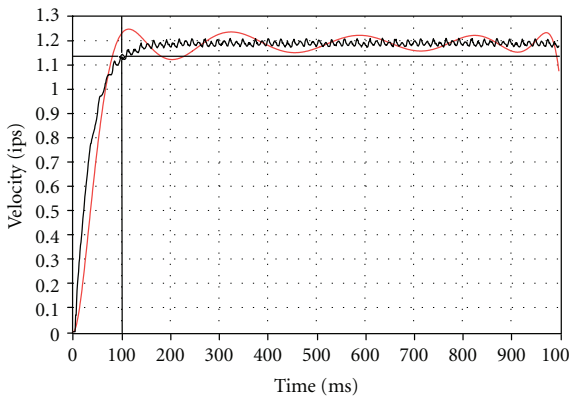
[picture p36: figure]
Time (ms); Velocity (ips)

0 100 200 300 400 500 600 700 800 900 1000

Figure 2: Approach w/o consideration of disturbance under 2 volt input: black, measurement: red, power series fitted.

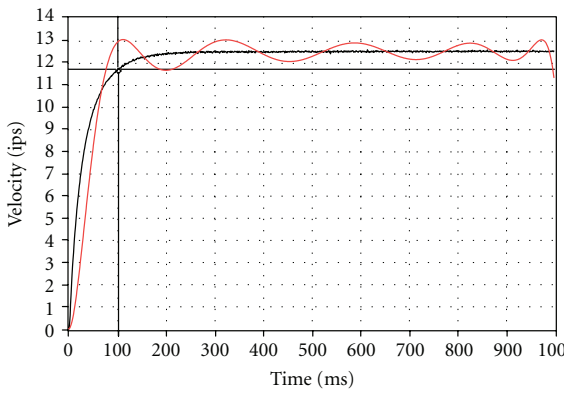
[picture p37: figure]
Time (ms); Velocity (ips)

0 100 200 300 400 500 600 700 800 900 1000

Figure 3: Approach w/o consideration of disturbance under 20 volt input:Black, measurement: Red, power series fitted.

### 4. Conclusions

A convenient, effective system identification approach is proposed to estimate the DC motor torque constant, mechanical time constant, electrical time constant, and friction. This approach was implemented on two Mabuchi motors, and the great test results were presented. This open-loop method requires little hardware, only a speed/position sensor and a voltage supply. The estimated motor parameters can be used to verify the DC motor performance or be used to build a model of the motor for the subsequent controller design or system optimization. This approach is especially suited to quick field applications.

### Appendix

Coefficients for no disturbance case are as follows:

| β0 = ab,
| β1 =−ab(a + b),

β2 = ab

| a2 + ab + b2 .

(A.1)

Modelling and Simulation in Engineering

5

Coe

fficients for disturbance case are as follows:

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
V0 kb
ab
,

β
2

=

16

V0 kb
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
+ ab
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
V0 kb
ab
a

2
+ ab
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
+ ab

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
+ ab
+

b

2

(A.2)

### References

[1] L. Ljiung, System Identification: Theory for the User, Prentice Hall, 2nd edition, 1999.
[2] H. Unbehauen and G. P. Rao, “A review of identification in continuous-time systems,” Annual Reviews in Control, vol. 22, pp. 145–171, 1998.
[3] G. F. Franklin, J. D. Powell, and M. L. Workman, Digital Control of Dynamic Systems, Addison Wesley, 2nd edition, 1990.
[4] J. C. Basilio and M. V. Moreira, “State-space parameter identification in a second control laboratory,” IEEE Transactions on Education, vol. 47, no. 2, pp. 204–210, 2004.
[5] G. Mamani, J. Becedas, H. Sira-Ramirez, and V. Feliu Batlle, “Open-loop algebraic identification method for DC motors,” in Proceedings of the European Control Conference, Kos, Greece, 2007.
[6] G. Mamani, J. Becedas, and V. Feliu-Batlle, “On-line fast algebraic parameter and state estimation for a DC motor applied to adaptive 16 control,” in Proceedings of the World Congress on Engineering, London, UK, 2008.
[7] R. Krneta, S. Antic, and D. Stojanovic, “Recursive least square method in parameters identification of DC motors models,” Facta Universitatis, vol. 18, no. 3, pp. 467–478, 2005.
[8] M. Hadef and M. R. Mekideche, “Parameter identification of a separately excited DC motor via inverse problem methodology,” in Proceedings of the Ecologic Vehicles andRenewable Energies, Monaco, France, 2009.
[9] M. Ruderman, J. Krettek, F. Ho

ffman, and T. Betran, “Optimal state space control of DC motor,” in Proceedings of the 17th World Congress IFAC, pp. 5796–5801, Seoul, Korea, 2008.
[10] M. Hadef, A. Bourouina, and M. R. Mekideche, “Parameter identification of a DC motor via moments method,” International Journal of Electrical and Power Engineering, vol. 1, no. 2, pp. 210–214, 2008.
[11] A. Rubaai and R. Kotaru, “Online identification and control of a dc motor using learning adaptation of neural networks,” IEEE Transactions on Industry Applications, vol. 36, no. 3, pp. 935–942, 2000.

# Journal of EngineeringVolume 2014

# The Scientific

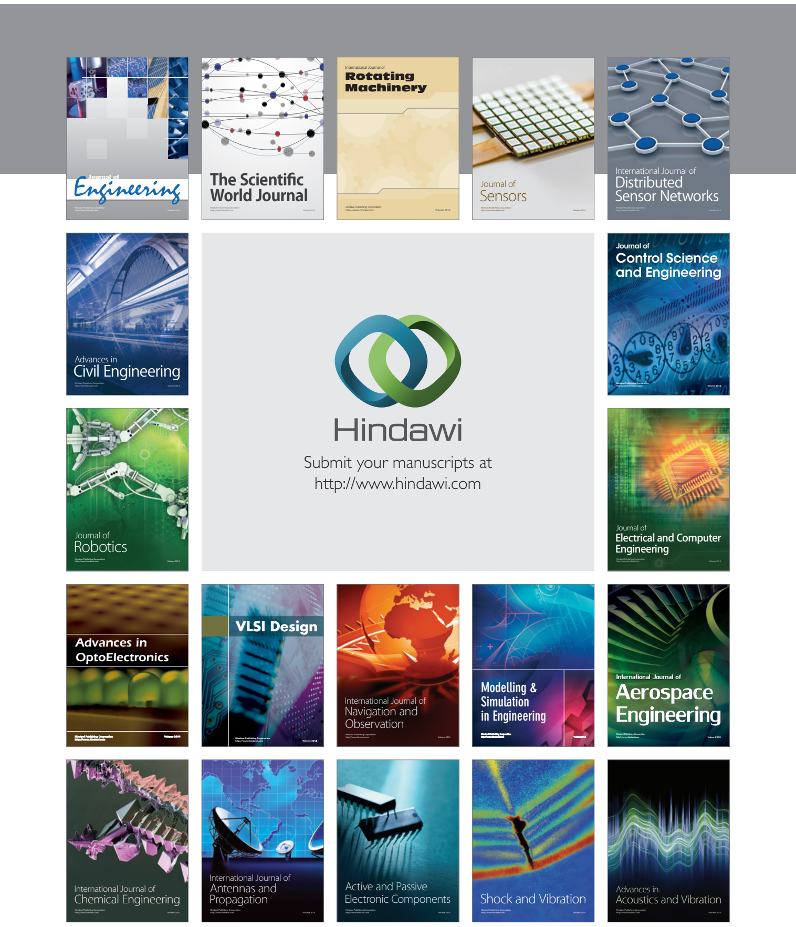
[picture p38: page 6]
http://www.hindawi.com; Volume 2010; Robotics; Journal of; Volume 2014; Control Science and Engineering; VLSI Design; Civil Engineering; Advances in; Advances in OptoElectronics; World Journal; Sensors; Modelling & Simulation in Engineering; Chemical Engineering; International Journal of; Antennas and

International Journal of
Rotating
Machinery

Distributed
Sensor Networks

Hindawi Publishing Corporation
http://www.hindawi.com

Submit your manuscripts at

Journal of
Electrical and Computer
Engineering

Aerospace

Navigation and
Observation

Propagation

Active and Passive
Electronic Components

Advances in
Acoustics and Vibration

Shock and Vibration

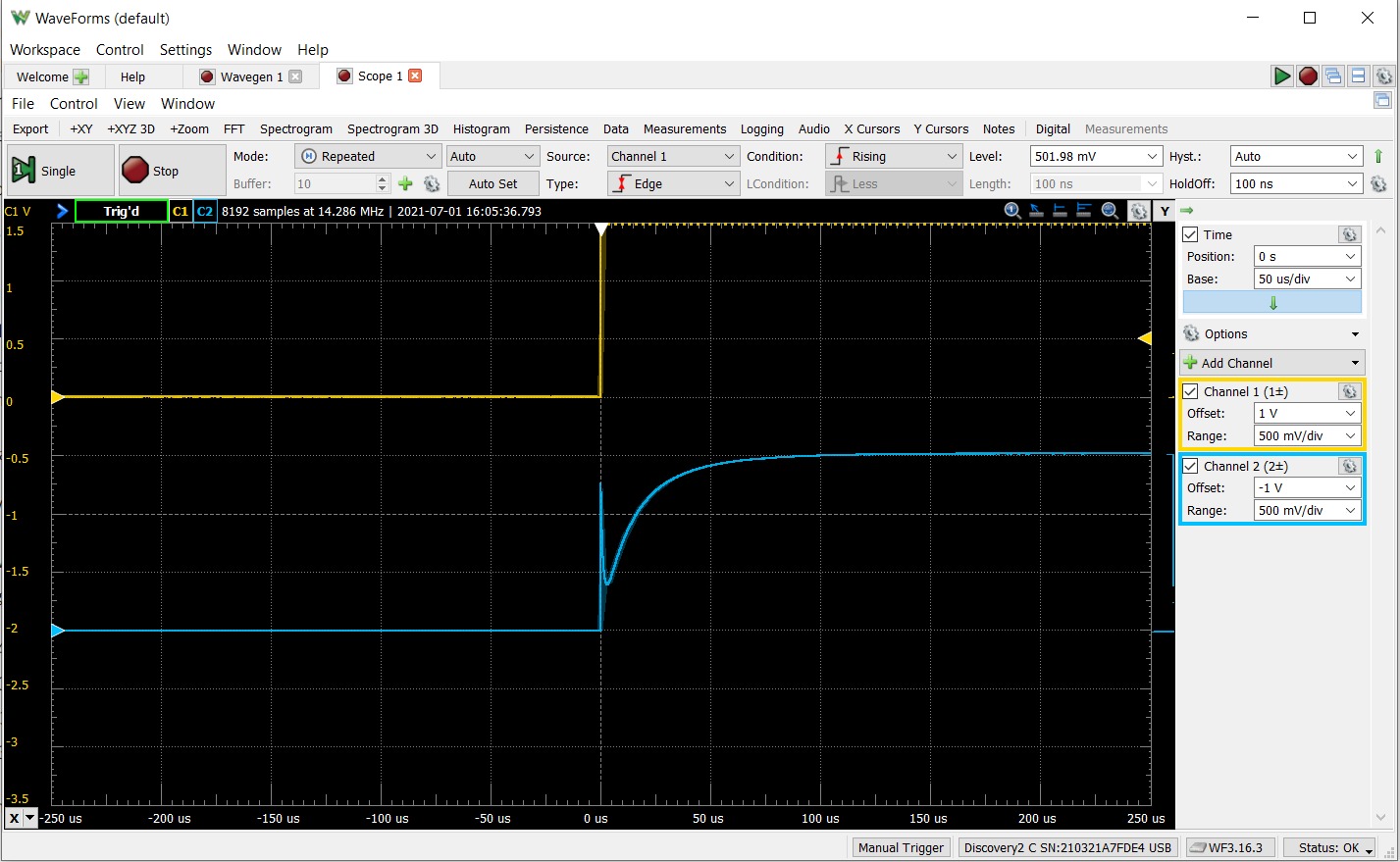
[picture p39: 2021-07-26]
Research/System_Identification/Step_100ohm.jpeg

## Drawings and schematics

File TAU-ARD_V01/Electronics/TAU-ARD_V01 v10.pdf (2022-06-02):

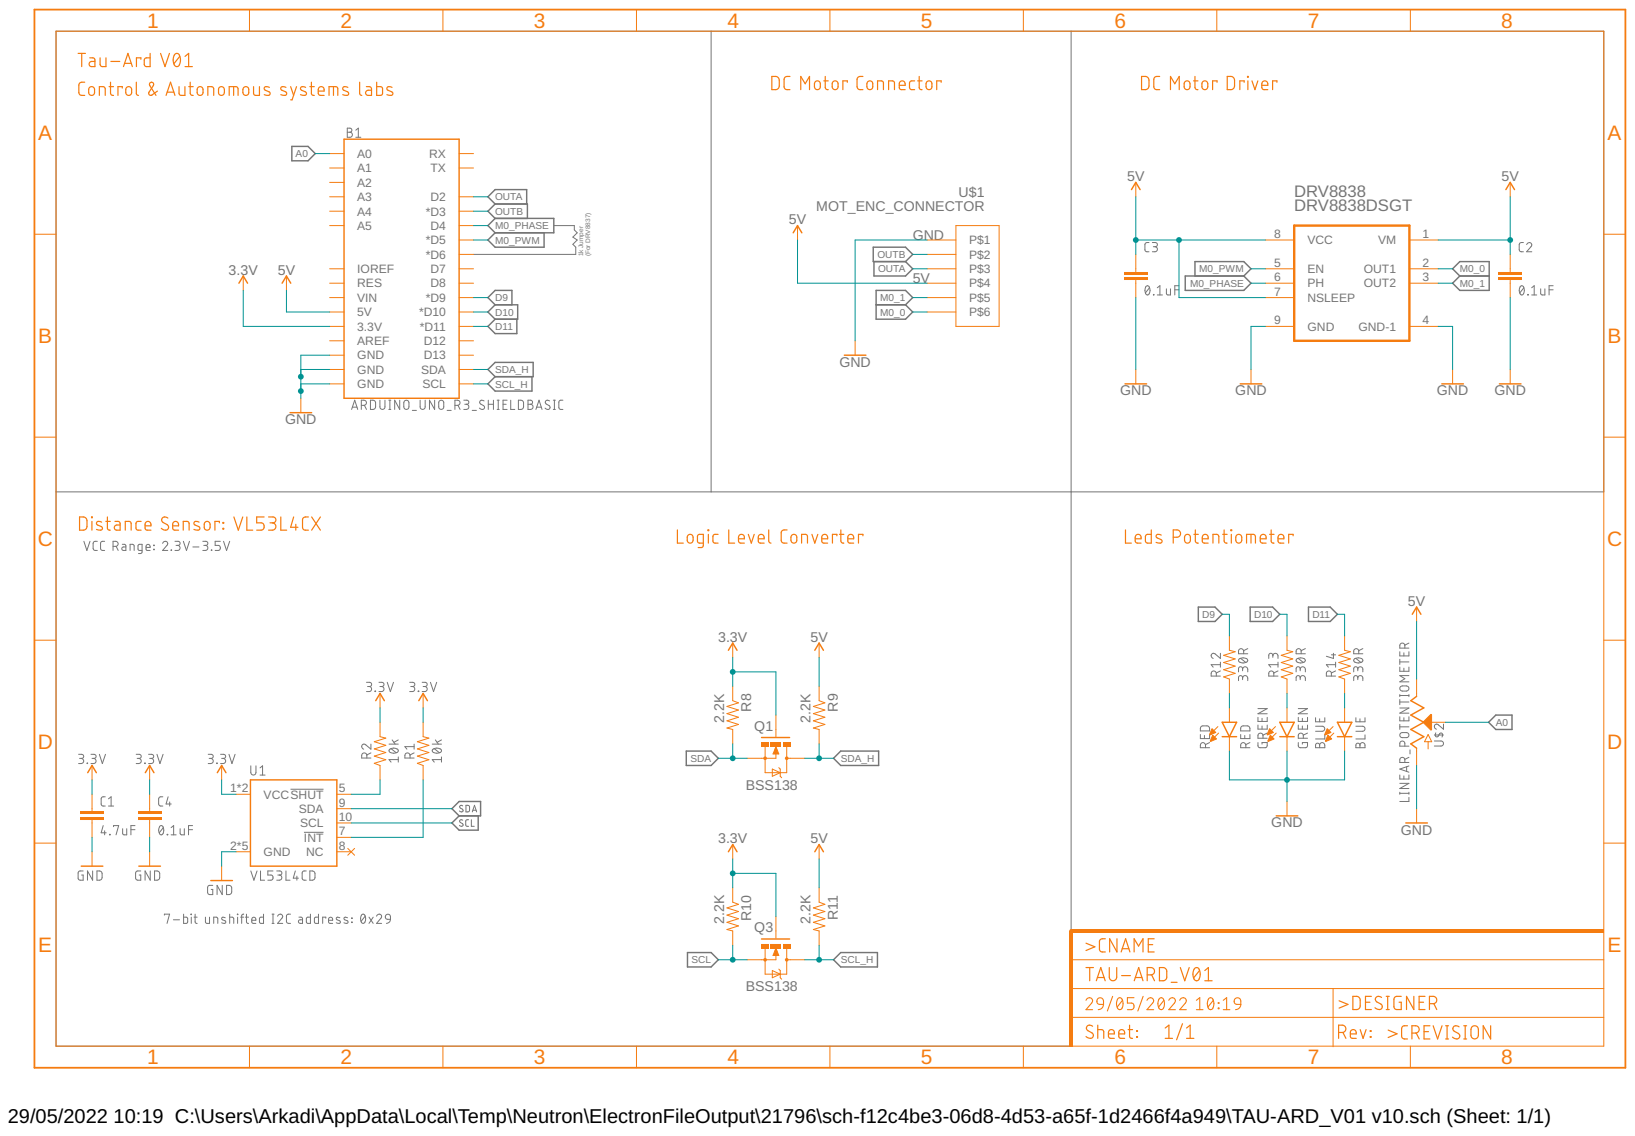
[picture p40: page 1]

29/05/2022 10:19 C:\Users\Arkadi\AppData\Local\Temp\Neutron\ElectronFileOutput\21796\sch-f12c4be3-06d8-4d53-a65f-1d2466f4a949\TAU-ARD_V01 v10.sch (Sheet: 1/1)

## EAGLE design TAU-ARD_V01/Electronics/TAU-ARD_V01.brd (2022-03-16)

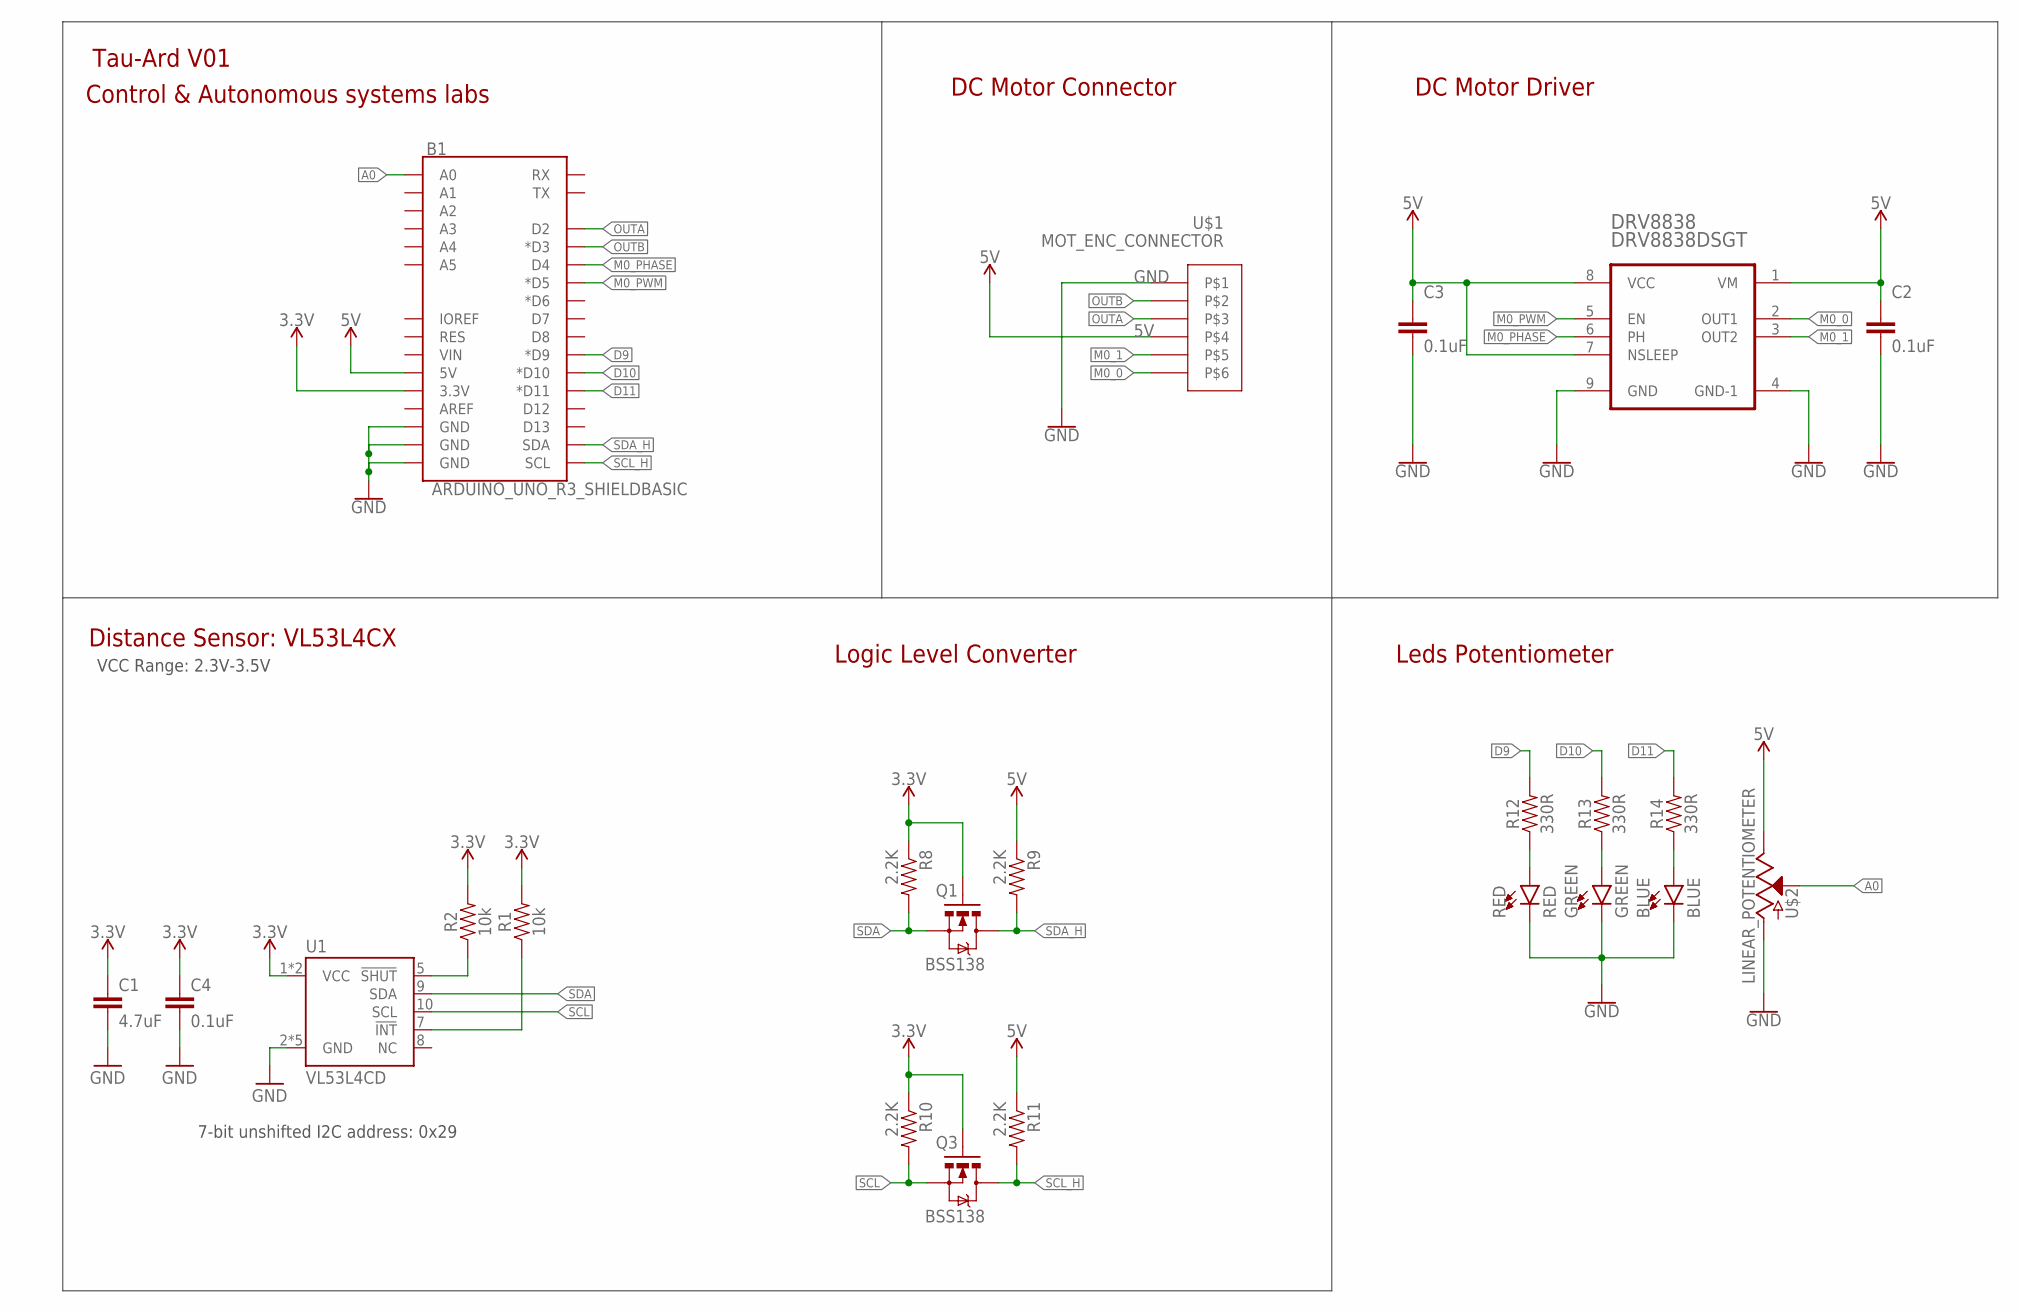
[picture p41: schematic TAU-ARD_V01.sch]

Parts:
B1: ARDUINO_UNO_R3_SHIELDBASIC; UNO_R3_SHIELD
BLUE: BLUE; LED-1206
C1: 4.7uF; 0603
C2, C3, C4: 0.1uF; 0603
DRV8838: DRV8838DSGT; SON50P200X200X80-9N
GREEN: GREEN; LED-1206
Q1, Q3: BSS138; SOT23-3
R1, R2: 10k; 0603
R8, R9, R10, R11: 2.2K; 0603-RES
R12, R13, R14: 330R; 0805
RED: RED; LED-1206
U1: VL53L4CD
U$1: MOT_ENC_CONNECTOR; 6X1_CONNECTOR_2MM_SMD
U$2: LINEAR_POTENTIOMETER; PTA2043

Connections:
3.3V: B1.3.3V, C1.1, C4.1, Q1.1 (G), Q3.1 (G), R1.2, R2.2, R8.1, R10.1, U1.1 (VCC), U1.11 (VCC)
5V: B1.5V, C2.1, C3.1, DRV8838.1 (VM), DRV8838.7 (NSLEEP), DRV8838.8 (VCC), R9.1, R11.1, U$1.P$4, U$2.TOP (VCC)
!INT: R1.1, U1.7 (!INT)
!SHUT: R2.1, U1.5 (!SHUT)
A0: B1.A0, U$2.WIPER (SIG)
D9: B1.D9 (*D9), R12.2
D10: B1.D10 (*D10), R13.2
D11: B1.D11 (*D11), R14.2
GND: B1.GND@0 (GND), B1.GND@1 (GND), B1.GND@2 (GND), BLUE.C, C1.2, C2.2, C3.2, C4.2, DRV8838.4 (GND-1), DRV8838.9 (GND), GREEN.C, RED.C, U1.2 (GND), U1.3 (GND), U1.4 (GND), U1.6 (GND), U1.12 (GND), U$1.P$1, U$2.BOTTOM (GND)
M0_0: DRV8838.2 (OUT1), U$1.P$6
M0_1: DRV8838.3 (OUT2), U$1.P$5
M0_PHASE: B1.D4, DRV8838.6 (PH)
M0_PWM: B1.D5 (*D5), DRV8838.5 (EN)
unnamed: R12.1, RED.A
unnamed: GREEN.A, R13.1
unnamed: BLUE.A, R14.1
OUTA: B1.D2, U$1.P$3
OUTB: B1.D3 (*D3), U$1.P$2
SCL: Q3.2 (S), R10.2, U1.10 (SCL)
SCL_H: B1.SCL, Q3.3 (D), R11.2
SDA: Q1.2 (S), R8.2, U1.9 (SDA)
SDA_H: B1.SDA, Q1.3 (D), R9.2

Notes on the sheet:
DC Motor Driver
Logic Level Converter
Tau-Ard V01
DC Motor Connector
Leds Potentiometer
Control & Autonomous systems labs
7-bit unshifted I2C address: 0x29
Distance Sensor: VL53L4CX
VCC Range: 2.3V-3.5V

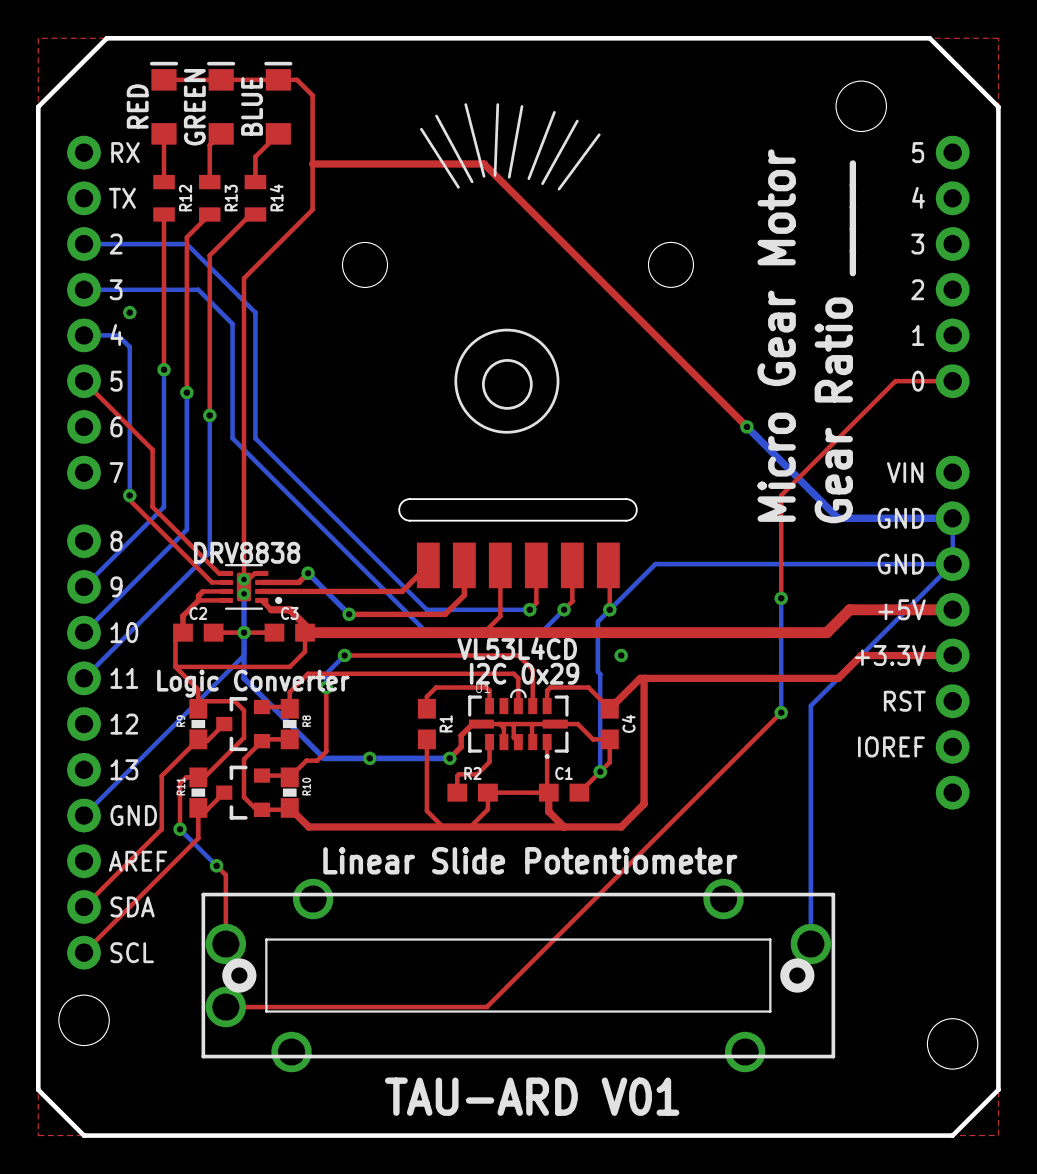
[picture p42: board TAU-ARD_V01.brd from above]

Board: 2 copper layers, 53.3 x 61.0 mm, 23 parts (0 on the bottom side), 22 nets.

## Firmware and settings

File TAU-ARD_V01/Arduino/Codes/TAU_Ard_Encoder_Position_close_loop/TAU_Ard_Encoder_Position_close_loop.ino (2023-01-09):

//Encoder Example

// Define Pins
#define ENCODER_PINA 2
#define ENCODER_PINB 3
#define LINEAR_POT A0
#define PWM1_PIN 6 // when jumper resistor is placed 4-->6 then switch to pin 6
#define PWM2_PIN 5
// encoder variables
volatile int encoderCounts = 0;

// Encoder ISR functions - Interupt Service Routine
void encoderA();
void encoderB();

String inputString = "";         // a String to hold incoming data
bool stringComplete = false;  // whether the string is complete

int dAngle = 0; // degrees
int dcounts = 0; // desired counts
void setup() {
  // initialize serial communication at 115200 bits per second:
  Serial.begin (115200);
  
  // initialize encoder, attache ISR functions
  pinMode(ENCODER_PINA, INPUT);
  pinMode(ENCODER_PINB, INPUT);
   // Attached interrupt to encoder pins
  attachInterrupt(digitalPinToInterrupt(ENCODER_PINA), encoderA, CHANGE);
  attachInterrupt(digitalPinToInterrupt(ENCODER_PINB), encoderB, CHANGE);

  Serial.print("DesiredAngle Angle");
}

void loop() {
  // print the string when a newline arrives:
  if (stringComplete) {
    //Serial.println(inputString);
    dAngle = inputString.toInt();
    dcounts = dAngle * 0.5; // 1 = 30 gear ration * 12 pulses / 360 degrees
    // clear the string:
    inputString = "";
    stringComplete = false;
    
  }
  
  //measured dt
  static long micro_tic = micros();
  long dt = micros() - micro_tic;
  float dt_f = dt / 1000000.0;
  micro_tic = micros();

  // int linearPotentiometer = analogRead(LINEAR_POT);
  // control loop implementation
  static float i_err = 0;
  float err = (float) (dcounts - encoderCounts);
  i_err = i_err + err*dt_f;
  float motorCMD = err*1.0 + i_err*1.0;
  if (motorCMD >= 255) motorCMD = 255;
  if (motorCMD <= -255) motorCMD = -255;
  
  if (motorCMD <= -1){
    digitalWrite(PWM2_PIN, LOW);
    analogWrite(PWM1_PIN, (int)-motorCMD);
  } else if (motorCMD >= 1) {
    digitalWrite(PWM1_PIN, LOW);
    analogWrite(PWM2_PIN, (int)motorCMD);
  } else {
    digitalWrite(PWM2_PIN, LOW);
    digitalWrite(PWM1_PIN, LOW);
  }
    int angle =  encoderCounts * 2; // 1 = 360 degree / 30 gear ration * 12 pulses 
    Serial.print (dAngle);
    Serial.print (" ");
    Serial.println(angle);
  delay(10);
}

/*
  SerialEvent occurs whenever a new data comes in the hardware serial RX. This
  routine is run between each time loop() runs, so using delay inside loop can
  delay response. Multiple bytes of data may be available.
*/
void serialEvent() {
  while (Serial.available()) {
    // get the new byte:
    char inChar = (char)Serial.read();
    // add it to the inputString:
    inputString += inChar;
    // if the incoming character is a newline, set a flag so the main loop can
    // do something about it:
    if (inChar == '\n') {
      stringComplete = true;
    }
  }
}

// EncoderA ISR
void encoderA() {
  // look for a low-to-high on channel B
  if (digitalRead(ENCODER_PINA) == HIGH) {
    // check channel A to see which way encoder is turning
    digitalRead(ENCODER_PINB) ? encoderCounts++ : encoderCounts--;    
  }else{
    // check channel A to see which way encoder is turning
    digitalRead(ENCODER_PINB) ? encoderCounts-- : encoderCounts++; 
  } 
} // End EncoderA ISR

// EncoderB ISR
void encoderB() {
  // look for a low-to-high on channel B
  if (digitalRead(ENCODER_PINB) == HIGH) {
    // check channel A to see which way encoder is turning
    digitalRead(ENCODER_PINA) ? encoderCounts-- : encoderCounts++;    
  }else{
    // check channel A to see which way encoder is turning
    digitalRead(ENCODER_PINA) ? encoderCounts++ : encoderCounts--; 
  }
} // End EncoderB ISR

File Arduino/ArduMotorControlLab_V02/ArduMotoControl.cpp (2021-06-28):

/* ArduMotoControl
*/

#include "Arduino.h"
#include "ArduMotoControl.h"

// encoder variables
volatile int encoderCounts = 0;
volatile unsigned long lastMicrosENCTick = 0;              // initilize with inf value
volatile unsigned long encoderDTmicros = 10000000;         // initilize with inf value
volatile unsigned long encoderDTmicrosFiltered = 10000000; // initilize with inf value
volatile int rotationDir = 1;


// motion profiles
// getnerate step commands 0,1,0,1... with a set period in secodns
float StepCMD(float stepPeriod){
  unsigned long stepPeriodMillis = (unsigned long)(stepPeriod*1000);
  float stepCmdValue = 0;
  if ((millis() % (stepPeriodMillis * 2)) >= stepPeriodMillis) stepCmdValue = 1;
  return stepCmdValue;
}

// generate ramp command with a set period in secodns
float RampCMD(float rampPeriod){
  unsigned long stepPeriodMillis = (rampPeriod * 1000);
  float rampCmdValue = 0;
  unsigned long rampMillis = millis() % stepPeriodMillis;
  rampCmdValue = float(rampMillis) / (rampPeriod * 1000);
  return rampCmdValue;
}

// generate sine wave [0..1]
float SineCMD(float f_Hz){
   float w_rads = f_Hz * TWO_PI;
   float sineWave = (sin(w_rads*float(millis())/1000.0)+1)/2;
   return sineWave;
}

// motor command update
void motorComand(float cntrlValue){
  // set constrains
  if (cntrlValue > 1) cntrlValue = 1;
  if (cntrlValue < -1) cntrlValue =-1;
  // update pwm & direction
  if (cntrlValue >= 0){
    analogWrite(PWM_PIN,int(cntrlValue * 255));
    digitalWrite(DIR_PIN,HIGH);
  }else{
    analogWrite(PWM_PIN,int(-cntrlValue * 255));
    digitalWrite(DIR_PIN,LOW);
  }  
}

// initialize encoder, attache ISR functions
void InitArduMotorControl(){
  
  // initialize
  pinMode(ENCODER_PINA, INPUT);
  pinMode(ENCODER_PINB, INPUT);
  pinMode(DIR_PIN, OUTPUT);
  pinMode(PWM_PIN, OUTPUT);
  digitalWrite(DIR_PIN,HIGH);
  analogWrite(PWM_PIN,0);

  // Attached interrupt to encoder pins
  attachInterrupt(digitalPinToInterrupt(ENCODER_PINA), encoderA, CHANGE);
  attachInterrupt(digitalPinToInterrupt(ENCODER_PINB), encoderB, CHANGE);
}

// conrol functions

// finalized read encoder functions based on averaging time between pulses
// read encoder RPM
float ReadRPM(){
    // calculate RPM from time between pulses
    if (encoderDTmicrosFiltered == 0) encoderDTmicrosFiltered = 1;
    // check if the motor has stopped
    unsigned long calculatedEncoderDT = encoderDTmicrosFiltered;
    if ((micros() - lastMicrosENCTick) > MINIMUM_ENCDT) { // analyze why its not perfect, 6 RPM MINIMUM_ENCDT 20000
      calculatedEncoderDT += (micros() - lastMicrosENCTick); // time from last pulse and the interval of the privious pulse
    }
    // float rpmEncoder = rotationDir * 60 * (1000000 / (float(encoderDTmicros) * ENCODER_PPR); // dt in microseconds with 3 pulses per revolution
    float rpmEncoder = rotationDir * ENCDT_RPM / float(calculatedEncoderDT); 
    return rpmEncoder;
}

// read encoder rad/s
float ReadRadS(){
    // calculate RadS from time between pulses
    if (encoderDTmicrosFiltered == 0) encoderDTmicrosFiltered = 1;
    // check if the motor has stopped
    unsigned long calculatedEncoderDT = encoderDTmicrosFiltered;
    if ((micros() - lastMicrosENCTick) > MINIMUM_ENCDT) { 
      calculatedEncoderDT += (micros() - lastMicrosENCTick); // time from last pulse and the interval of the privious pulse
    }
    // float rpmEncoder = rotationDir * (1000000 / (float(encoderDTmicros) * ENCODER_PPR) * TWO_PI); // dt in microseconds with 3 pulses per revolution
    float rpmEncoder = rotationDir * ENCDT_RADS / float(calculatedEncoderDT);
    return rpmEncoder;
}

// RPM measured from number of pulses between function calls
float readRPMEncoder(){
    static unsigned long lastMillisEnc = 0;
    static unsigned int lastEncoderPos = 0;
    static unsigned int encoderPos = 0;
    unsigned long dtMillisEnc = (millis() - lastMillisEnc);
    if (dtMillisEnc == 0) dtMillisEnc = 1;
    lastMillisEnc = millis(); 
    lastEncoderPos = encoderPos;
    encoderPos = encoderCounts;
    int encoderPulses = encoderPos - lastEncoderPos;
    // float rpmEncoder = 60 * (((float(encoderPulses)) * 1000 / float(dtMillisEnc)) / ENCODER_CPR); // 12 pulses per revolution
    float rpmEncoder =  ENCPULSES_RPM * (float(encoderPulses) / float(dtMillisEnc));
    return rpmEncoder;
} 

// RPM measured from number of pulses between function calls
float readRadSEncoder(){
    static unsigned long lastMillisEnc = 0;
    static unsigned int lastEncoderPos = 0;
    static unsigned int encoderPos = 0;
    unsigned long dtMillisEnc = (millis() - lastMillisEnc);
    if (dtMillisEnc == 0) dtMillisEnc = 1;
    lastMillisEnc = millis(); 
    lastEncoderPos = encoderPos;
    encoderPos = encoderCounts;
    int encoderPulses = encoderPos - lastEncoderPos;
    //float RadSEncoder = (((float(encoderPulses)) * 1000 / float(dtMillisEnc)) / ENCODER_CPR * TWO_PI); // 12 pulses per revolution
    float RadSEncoder = ENCPULSES_RADS * (float(encoderPulses) / float(dtMillisEnc));
    return RadSEncoder;
}

// RPM measured from dt between pulses more precise at lower speeds       
float readRPMdtEncoder(){
    // calculate RPM from time between pulses
    if (encoderDTmicros == 0) encoderDTmicros = 1;
    // check if the motor has stopped
    unsigned long calculatedEncoderDT = encoderDTmicros;
    if ((micros() - lastMicrosENCTick) > MINIMUM_ENCDT) { 
      calculatedEncoderDT += (micros() - lastMicrosENCTick); // time from last pulse and the interval of the privious pulse
    }
    // float rpmEncoder = rotationDir * 60 * (1000000 / (float(encoderDTmicros) * ENCODER_PPR); // dt in microseconds with 3 pulses per revolution
    float rpmEncoder = rotationDir * ENCDT_RPM / float(calculatedEncoderDT); 
    return rpmEncoder;
} 
// RPM measured from dt between pulses more precise at lower speeds 
float readRadSdtEncoder(){
    // calculate RPM from time between pulses
    if (encoderDTmicros == 0) encoderDTmicros = 1;
    // check if the motor has stopped
    unsigned long calculatedEncoderDT = encoderDTmicros;
    if ((micros() - lastMicrosENCTick) > MINIMUM_ENCDT) { 
      calculatedEncoderDT += (micros() - lastMicrosENCTick); // time from last pulse and the interval of the privious pulse
    }else{
      calculatedEncoderDT = encoderDTmicrosFiltered;
    }
    // float rpmEncoder = rotationDir * (1000000 / (float(encoderDTmicros) * ENCODER_PPR) * TWO_PI); // dt in microseconds with 3 pulses per revolution
    float rpmEncoder = rotationDir * ENCDT_RADS / float(calculatedEncoderDT);
    return rpmEncoder;
}
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

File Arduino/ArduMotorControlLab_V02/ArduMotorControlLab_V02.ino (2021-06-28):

/* ArduMoto Control 28/06/2021

   Arduino Uno
   Sparkfun Ardumoto shield Dev-14129
   
*/
#include "ArduMotoControl.h"

// define constants
#define DT_CONTROL_MILLIS 10  // Control DT suggested range 5-50 mSec --> 200-20 Hz
#define GEAR_RATIO 29.86     // Motor gear ratio
#define TIMEOUT 5            // Experiment length in seconds

// timeout flag
boolean timeOutFlag = 0;

// Control Variables
float encoderRADSdt = 0;
float encoderRADSPulses = 0;
float motorRPMdt = 0;
float motorRPMPulses = 0;

// control loop function
void MotorControlLoop(void);
// Control function
float MotorControl(float desiredCMD);

// Init setup
void setup() {
  // intinitalize encoder
  InitArduMotorControl();
  pinMode(LED_BUILTIN, OUTPUT);
  
  // init serial
  Serial.begin (115200);
  //////////////////////////////
  //////// Student Code ////////
  //////////////////////////////
  
  // serial plotter legend
  Serial.println("DesireCMD, MotorCMD, Error, RPMdt, MCUload");
  
  //////////////////////////////
  //// End of student Code /////
  //////////////////////////////
}

void loop() {
  if (!timeOutFlag){
    static unsigned long millisTick = millis();
    if (millisTick >= TIMEOUT*1000) timeOutFlag = 1;
    
    // control loop software implementation
    if ((millis() - millisTick) >= DT_CONTROL_MILLIS){
      millisTick = millis();
      unsigned long microsTick = micros(); // simple loop cpu consumption measurement
      digitalWrite(LED_BUILTIN,HIGH);

      // update Motor RPM variables
      encoderRADSdt = ReadRadS(); // rad/s measured from dt between pulses with averaging
      encoderRADSPulses = readRadSEncoder(); // rad/s measured from number of pulses over control period 
      motorRPMdt = encoderRADSdt / GEAR_RATIO * RADS_RPM;
      motorRPMPulses = encoderRADSPulses / GEAR_RATIO * RADS_RPM;
      
      //////////////////////////////
      //////// Student Code ////////
      //////////////////////////////

      // motor control loop function call
      MotorControlLoop();

      //////////////////////////////
      //// End of student Code /////
      //////////////////////////////

      //debug code consumption better alternativelyy measure d13 duty cycle / frequency
      Serial.print(" , ");
      Serial.println((micros()-microsTick)/100); // value in % for control loop
      digitalWrite(LED_BUILTIN,LOW);
    }
  }else{
      // turn off motor
      motorComand(0);
  }
}

//////////////////////////////
////// Student functions /////
//////////////////////////////

// control loop function
void MotorControlLoop(void){
  // Command profile
  // float desiredCMD = 100 * StepCMD(2); // step command, input period seconds
  // float desiredCMD = 100 * RampCMD(2); // Ramp command, input period seconds
  float desiredCMD = 300 * SineCMD(0.5);  // Sine command, input Hz
  
  // motor control function
  float motorCMD = MotorControl(desiredCMD);
  
  // update motor, values range of [-1..1]
  motorComand(motorCMD);

  // openloop
  //motorComand(desiredCMD / 200);

  // send values to serial plotter
  Serial.print(desiredCMD);
  Serial.print(" , ");
  Serial.print(motorCMD*100); // scaled to 100% to be visible on plot
  Serial.print(" , ");
  Serial.print(desiredCMD - motorRPMdt);
  Serial.print(" , ");
  Serial.print(motorRPMdt); // motorRPMPulses
} 

// control loop function
float MotorControl(float desiredCMD){
  // initialize variables
  static float dt = DT_CONTROL_MILLIS / 1000.0;
  static float ciEr = 0; // integral error
  static float cdEr = 0; // differamtial error
  static float cEr  = 0; // current error
  static float lEr  = 0; // last error
  
  // control coefficients
  float kp = 0.002/3;
  float ki = 0.05/3;
  float kd = 0.00005/3;
  
  // update error
  lEr = cEr;
  //float cEr = desiredCMD - motorRPMPulses;
  cEr = desiredCMD - motorRPMdt;
  ciEr = ciEr + cEr*dt;
  cdEr = (cEr- lEr) / dt;
  
  // clip integrator error
  if (ciEr*ki > 2.5) ciEr = 2.5/ki;
  if (ciEr*ki < -2.5) ciEr = -2.5/ki;

  // update control command
  float motorCMD = kp*cEr + ki*ciEr + kd*cdEr;

  // Optional - As it is clipped in library.
  // clip motor command
  // if (motorCMD > 1) motorCMD = 1;
  // if (motorCMD < -1) motorCMD = -1;
  
  // Optional
  // dead zone + preamp
  //if (abs(motorCMD) < 0.05) motorCMD = 0; // dead zone
  //if ((motorCMD >= 0.05) && (motorCMD < 0.075)) motorCMD = 0.075; // preamp
  //if ((motorCMD <= -0.05) && (motorCMD > -0.075)) motorCMD = -0.075; // preamp

  return motorCMD;
}

//////////////////////////////
// End of Student functions //
//////////////////////////////
 

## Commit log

2021-02-22 discrete control V02
    V02 - Moved gear ratio to main code, updated conversion constants accordingly, Added timeout variable
2021-06-28 fix library
    fix to correct initialize of encoder reading values.
    [ArduMotoControl.cpp, ArduMotorControlLab_V02.ino]

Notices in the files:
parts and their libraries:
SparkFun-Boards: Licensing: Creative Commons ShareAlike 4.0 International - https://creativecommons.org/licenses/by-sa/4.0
